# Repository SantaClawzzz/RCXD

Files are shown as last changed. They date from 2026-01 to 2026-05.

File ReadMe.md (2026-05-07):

## Introduction
Project repository for RC-XD project<br>
A remote controlled car Robotics Club project and Bachleor's thesis

The project is divided into 3 parts: Electronics, Mechanics, Programming<br>
Seperated by folders and ReadMe files on each of them.

### Design description

The project design description can be found [HERE](https://1drv.ms/w/c/367a3aeb31e11553/IQC-Zez4F6-2QIbnWiFFyMPwAU7Qmx2ZVu3_AnnbPPWjXhY?e=D11Og5)

### Timeline

The project timeline is [HERE](https://docs.google.com/document/d/1Baed8mpfqgpyJ5yqUqOmzXT9Kg_jJRIP0yAwD-ANLqw/edit?usp=sharing)

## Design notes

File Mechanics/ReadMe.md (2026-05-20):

# Info

All 3D print files for the car and controller adapter<br>
Small proto of the unfinished 433MHz controller

PCB files are also exported.

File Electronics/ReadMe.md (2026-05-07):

# Info
The PCBs both have 2 major revisions, (TMC and PreIDC have never been ordered).<br>
The newer ones will be documented with only changes mentioned about the previous revisions.

No document except the design description is present.

# TX

The transmitter PCB is essentialy the controller. Most of it is buttons and joystick routing with IDC connectors.<br>
Also includes 3.3V and 5V LDO regulators, where 5V is unused and routed to external header. 3.3V powers the MCU and logic pull-ups.<br>

## Components

The project has had 3 MCUs:
MCU:
  * ATMega328p-AU
  * ESP32-C6-WROOM-1U
  * STM32F103Cx

Buttons and joystick are routed to IDC headers which are easier to crimp by hand and allows for the mechanical design to be flexible. TX header is still the default 2.54mm header, which connection can be concerning as it doesn't have any locking mechanism.

Design is done with panelization in mind, so not every switch and joystick has to be ordered separately.
This only benefitial with larger quantities

* MCU - [STM32F103C6](/Electronics/Datasheets/stm32f103c6.pdf)
* Backup MCU [STM32F103C8](/Electronics/Datasheets/stm32f103c8.pdf)
* USB-UART chip [HT42B534-2](/Electronics/Datasheets/HT42B534-xv130.pdf)
* Battery - 7.4V [TBA]()
* Regulators:
  * [3V3 LDO](/Electronics/Datasheets/AMS1117.pdf)
  * [5V LDO](/Electronics/Datasheets/AMS1117-5.0.pdf)
* [USB-C](/Electronics/Datasheets/GCT_usb4085.pdf)
* [Button](/Electronics/Datasheets/TL2201.pdf)
* [Joystick](/Electronics/Datasheets/thb001p.pdf)
* [FS1000A](/Electronics/Datasheets/FS1000A_webpage.pdf) and the [module](/Electronics/Datasheets/433%20MHz%20RF%20Transmitter%20Module_0.pdf)

433MHz didn't work well, so TX was pushed aside and Flysky controller was brought in to use
* [FS-i6X](https://www.flysky-cn.com/fsi6x)

## Mechanical parameters:
  * 34.5mm x 80mm
    * Joystick (30mm x 24mm)
    * Button (16mm x 19mm)
    * MCU (34.5mm x 27.5mm)
  * M2 screws

## Power

LDOs are used since max current is ~100mA. 5V LDO is unused but connects with USB-C VBUS and cascades into 3.3V LDO. 5V is routed to an external header for possible future use.
Switching regulators take more space, cost more and require more thought into the design. Since there is no need, there is no need to use extra resources.

## Logic

For the logic and data processing the STM32F103Cx is used. C6 and C8 both have identical pinouts and only differ by the internal RAM size.<br>
STM32F103C6/8 design is based of the "Blue pill" and can be programmed in Arduino or STM32. STM is preferable as it gives lower level access and has faster data processing.<br>
A lot of pins are unused and this could be considered overkill for this design but it's the same MCU used for the RX, which saves time on complications and differences on the two boards.

# RX

The receiver PCB is mostly the motor driver with logic being received from the RX PCB. So power paths are most crucial part of the design. It's quite tight and might have some errors.<br>
Instead of LDOs, switching regulators are used since the current draw is much higher.

## Components
The project has had 2 MCU and 1 motor driver change:
MCU:
  * ATMega328p-AU
  * ESP32-C6-WROOM-1U
  * STM32F103Cx

The STM chip has good ADC readings, USB OTG, reliable, librarys for STM32CubeIDE and Arduino and available resources / designs like the STM32 "Blue Pill"<br>
The video (which was planned at first with ESP32) will be done externally, with seperate VTX/RTX modules

DRV:
  * TMC5160/A
  * BTM9011

BTM chip was chosen after it was determined the TMC chip is for stepper motors and controls them assuming they're on one axis (meaning if ones slows down, is fked)
So with the BTM chip we gain:
  * Internal MOSFETS, so smaller design
  * Cheaper chip: 1.5€ vs 7€ (not including the external components)
  * Less complicated (PCB design as well as programming/datasheet)
  * Does what we actually want
  * Also it has current sensing and should have under- and overvoltage protection with current/stall protection

* MCU - [STM32F103C6](/Electronics/Datasheets/stm32f103c6.pdf)
* Backup MCU - [STM32F103C8](/Electronics/Datasheets/stm32f103c8.pdf)
* USB-UART chip [HT42B534-2](/Electronics/Datasheets/HT42B534-xv130.pdf)
* Driver - [BTM9011](/Electronics/Datasheets/BTM901xep.pdf)
* Battery - 12V [TBA]()
* Motors - [Pololu 4842](https://www.pololu.com/product/4842)
* Regulators - [5V buck](/Electronics/Datasheets/REN_RAA211803.pdf) and [3V3 LDO](/Electronics/Datasheets/NCP115-D.pdf)
* USB-C - [THT variant](/Electronics/Datasheets/GCT_usb4085.pdf)

* Includes headers for:
  * 3x [TOF](https://www.pololu.com/product/3415) sensors (I2C)
  * 1x [OLED](https://www.adafruit.com/product/931?srsltid=AfmBOooS0SgYaJRqBKaiZJ_inS_Hm55apfdVYE57VtUnGSEqd8KzymMf) screen (I2C) - No RST or VIN
  * 1x [XY-MK-5V](https://radiolux.com.ua/files/pdf/RFmodule.pdf) (GPIO)
  * 1x [FS-A8s](https://www.flysky-cn.com/a8sspecifications)

## Power
* 3S 12V battery, since motors are 12V
* 5A stall current but under load should hover less than 1A
* USB-C for programming and VBUS through diode to 5V

Main issue right now is the power for the motors, since they take 1A probably by normal and 5A at stall. So the traces should withstand 5A, but they at max withstand 2A.<br>
This should be fine but might need a redesign with v2 or even before the first batch.<br>
Also an idea is active cooling, so if the PCB can't withstand it maybe with active cooling it can

## Mechanical parameters
  * 37x40mm
  * M2 screws

## Logic

For the logic the same STM32F103Cx MCU is used.<br>
It takes in data from the TX PCB and gives signals to the drivers, gets data through SPI from drivers and also current sense which it has to do on RX board since it has no way of sending info to the TX board.<br>
Some extra pins are drawn to unused GPIO headers.

# VX

Video part is completely seperate system, no PCB currently but schematic is made in Altium<br>
Mostly plug and play, TX06 camera only need power (4 in 1 system).<br>
Receiver needs 2 electrolytic capacitors (470uF), wiring and antenna. Video soldered straigth to display, needs to have proper RCA jack

## Components
* Car
  * [TX06](https://www.eachine.com/Eachine-TX06-700TVL-FOV-130-Degree-5_8Ghz-40CH-Smart-Audio-Mini-FPV-Camera-AIO-Transmitter-For-RC-Dr-p-1418.html)
  * 1S battery - Picture below
* Controller
  * Protoboard
  * 2x 470uF electrolytic capacitors
  * [U.FL antenna connector](https://www.digikey.com/en/products/detail/te-connectivity-amp-connectors/2337019-1/9974052)
  * [Antenna](https://www.digikey.com/en/products/detail/yic/ATIF2458G-3010/21804188)
  * Screen - Picture below
  * 2S or 3S battery

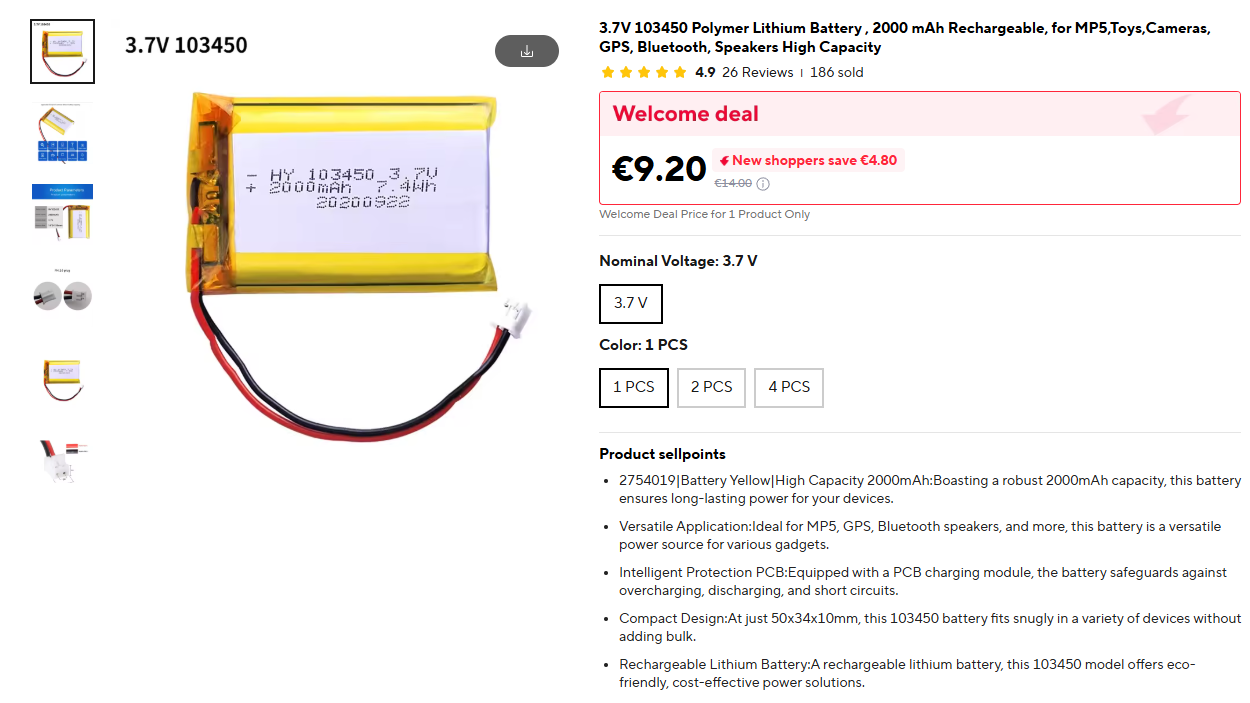
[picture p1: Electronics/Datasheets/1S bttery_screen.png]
battery

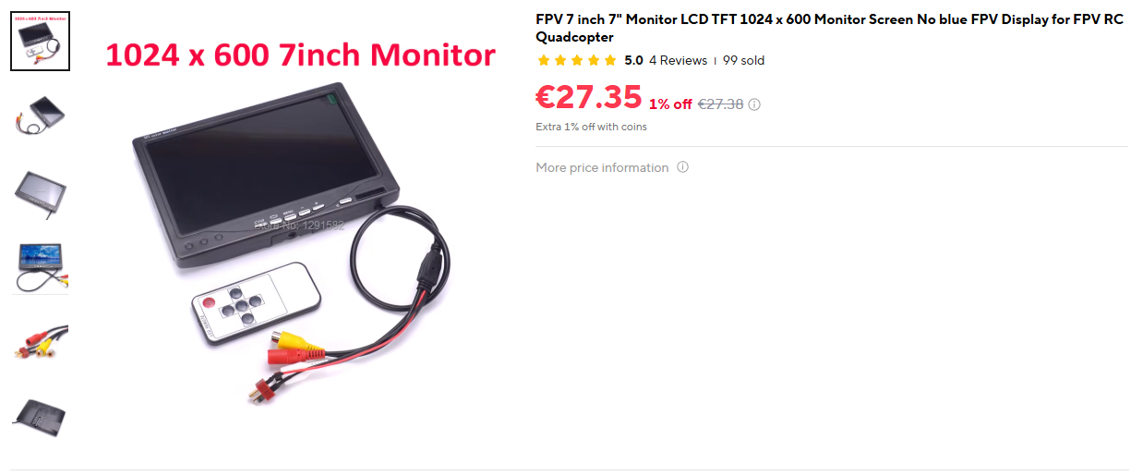
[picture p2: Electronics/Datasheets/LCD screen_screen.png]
screen


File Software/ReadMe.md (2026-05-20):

# Info

This folder contains all STM32 firmware projects for the RC-XD, written in STM32CubeIDE using HAL.<br>
All three projects target the STM32F103Cx (C6 or C8 — identical pinout, differ only in flash/RAM size).

## Projects

### TX_C6 — 433 MHz Transmitter (deprecated)

Custom transmitter firmware for the TX PCB.<br>
Reads joystick position via ADC, encodes a BTM9011 motor command, and transmits it over 433 MHz using the FS1000A module with a custom RF433 driver (RadioHead RH_ASK compatible, 2000 bps OOK).<br>
Abandoned because 433 MHz performance was too unreliable.

### RX_C8 — 433 MHz Receiver (deprecated)

Companion receiver firmware for the RX PCB, paired with TX_C6.<br>
Receives 433 MHz packets via the XY-MK-5V module and forwards decoded commands to two daisy-chained BTM9011 motor drivers over SPI.<br>
Abandoned alongside TX_C6 when 433 MHz was dropped.

### RX_C6 — iBUS Receiver (current)

Current working firmware for the RX PCB.<br>
Replaces the custom 433 MHz link with the Flysky FS-A8s 2.4 GHz receiver, reading channel data via the iBUS protocol over UART with DMA.<br>
Controls two daisy-chained BTM9011 motor drivers and a servo, with deadzone handling and clamped PWM steps.

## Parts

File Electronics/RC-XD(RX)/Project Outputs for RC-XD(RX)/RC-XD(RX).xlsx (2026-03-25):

Comment | Description | Designator | Footprint | LibRef | Quantity
4.7u | MLCC, 0603, 4.7u, 10%, 35V, X5R | C200, C201 | MLCC_0603_M | CMP-001-1257-1 | 2
100n | MLCC, 0603, 100n, 10%, 35V, X7R, MLCC, 0603, 100n, 10%, 50V, X7R | C202, C203, C400, C401, C402, C404, C409, C411, C500, C501, C502, C503, C504, C505 | MLCC_0603_M | CMP-001-0755-1, CMP-001-0815-1 | 14
15p | MLCC, 0603, 15p, 5%, 50V, C0G/NP0 | C204, C205 | MLCC_0603_M | CMP-001-0474-1 | 2
1u | MLCC, 0603, 1u, 10%, 50V, X5R | C300, C301, C408, C410 | MLCC_0603_M | CMP-001-0565-1 | 4
22u | MLCC, 0603, 22u, 10%, 16V, X5R | C303, C304 | MLCC_0603_M | CMP-001-1264-1 | 2
4.7u | MLCC, 1206, 4.7u, 10%, 35V, X5R | C305 | MLCC_1206_M | CMP-001-1124-2 | 1
4.7u | MLCC, 0805, 4.7u, 20%, 50V, X5R | C403 | MLCC_0805_M | CMP-001-1830-1 | 1
15p | MLCC, 0402, 15p, 10%, 25V, C0G/NP0 | C405, C406 | MLCC_0402_M | CMP-001-1853-1 | 2
1n | MLCC, 0603, 1n, 10%, 50V, X5R | C407 | MLCC_0603_M | CMP-001-0547-1 | 1
MBR1020VL_R1_00001 | Rectifier Diode, Schottky, 1 Phase, 1 Element, 1A, 20V V(RRM), Silicon | D300, D400 | FP-MBR1020VL_R1_00001-MFG | CMP-ROOT-01310-1 | 2
VSSAF3M10HM3/H | Rectifier Diode, Schottky, 1 Phase, 1 Element, 2.3A, 100V V(RRM), Silicon, DO-221AC | D302 | VSSAF3M10HM3_H-Footprint-1 | CMP-ROOT-01308-1 | 1
Red | Generic red 0603 LED | D303, D304, D305, D306 | 0603 RED LED | CMP-ROOT-00025-2 | 4
1N5817G | Rectifier Diode, Schottky, 1 Phase, 1 Element, 1A, 20V V(RRM), Silicon, DO-204AL | D401 | SOD-323 based on 1N5817WS | CMP-ROOT-01323-1 | 1
XT30U-F | Power Connector | J300 | XT30U-F | CMP-ROOT-01262-3 | 1
USB4085-GF-A | USB Connector, 16 Contact(s), Female, Right Angle, Solder Terminal, Locking, Receptacle | J400 | FP-USB4085-GF-A-MFG | CMP-001-1800-1 | 1
7-215079-6 | Conn FFC Connector F 6 POS 1.27mm Solder ST Thru-Hole Automotive Box/Carton | J500, J501, J502 | 7-215079-6-Footprint-1 | CMP-ROOT-01311-2 | 3
0878310641 | Conn Shrouded Header (2 Sides) HDR 6 POS 2mm Solder ST Top Entry Thru-Hole Milli-Grid Tube | J503, J504 | 0878310641 | CMP-ROOT-01318-3 | 2
74404043220A | General Purpose Inductor, 22uH, 20%, 1 Element, Nickel-zinc Ferrite-Core, SMD, 1616 | L301 | WE-LQS_4025 | CMP-ROOT-01309-1 | 1
PH1-04-UA | 4 POS 2.54mm Vertical THT Header | P500 | 4Pos Pin Header Vertical | CMP-002-000004-1 | 1
M20-9990345 | Connector Header Through Hole 3 position 0.100" (2.54mm) | P503 | 3Pos Pin Header | CMP-ROOT-00217-1 | 1
61300511121 | Conn Unshrouded Header HDR 5 POS 2.54mm Solder ST Top Entry Thru-Hole Bag | P504, P505 | 61300511121 | CMP-ROOT-01020-1 | 2
2k | Resistor, 0603, 2k, 1%, 1/10W | R200 | Resistor_0603_M | CMP-001-0084-2 | 1
22R | Resistor, 0603, 22R, 1%, 1/10W | R201, R202, R203, R204, R205, R206, R207, R405, R406, R500 | Resistor_0603_M | CMP-001-0038-3 | 10
680R | Resistor, 0603, 680R, 1%, 1/10W | R300 | Resistor_0603_M | CMP-001-0074-3 | 1
200R | Resistor, 0603, 200R, 1%, 1/10W | R301, R303 | Resistor_0603_M | CMP-001-0060-2 | 2
100R | Resistor, 0603, 100R, ≤5%, ≥1/16W, Resistor, 0603, 100R, 1%, 1/10W | R302, R401, R504 | Resistor_0603_M | CMP-0001-00262-1, CMP-001-0054-5 | 3
10k | Resistor, 0603, 10k, 1%, 1/10W, Resistor, 0603, 10k, ≤5%, ≥1/16W | R400, R501, R502, R503 | Resistor_0603_M | CMP-001-0101-2, CMP-0001-00257-1 | 4
5.1k | Resistor, 0603, 5.1k, 1%, 1/10W | R402, R403 | Resistor_0603_M | CMP-001-0094-2 | 2
1.5k | Resistor, 0603, 1.5k, 1%, 1/10W | R404 | Resistor_0603_M | CMP-001-0081-2 | 1
1M | Resistor, 1206, 1M, 1%, 1/4W | R407 | Resistor_1206_M | CMP-0001-00051-1 | 1
4.7k | Resistor, 0603, 4.7k, 1%, 1/10W | R409, R410 | Resistor_0603_M | CMP-001-0093-2 | 2
USLPT2819DT4TR | Keypad Switch, SPST, 0.05A, 1.96N, Solder Terminal, Panel Mount | S400 | USLPT2819DT4TR-Footprint-1 | CMP-ROOT-01290-1 | 1
BTM9011EPXUMA1 | DC Mtr Drive, Brush, 150DEGC, TSSOPEP-14 Rohs Compliant: Yes | U200, U201 | BTM9011EPXUMA1 | CMP-00022-3 | 2
NCP115ASN330T2G | LDO Regulator, 300 mA, Low Iq, High PSRR, High Accuracy 3.3V, TSOP5, Active Discharge, Normal Vout Slew-Rate | U300 | TSOP-5 | CMP-00026-1 | 1
RAA2118054GP3#JA0 | Switching Regulator, Current-mode, 0.3A, 230kHz Switching Freq-Max, PDSO5 | U301 | P5_064B_MFG | CMP-00019-3 | 1
STM32F103C8T6 | MCU 32-bit STM32F1 ARM Cortex M3 RISC 64KB Flash 2.5V/3.3V 48-Pin LQFP Tray | U400 | STM-LQFP48_M | CMP-00012-3 | 1
HT42B534-2 | USB to UART 3Mbps USB 2.0 SOP-8 Interface Controllers RoHS | U401 | SOP-8 150mil | CMP-00027-2 | 1
XY-MK-5V RF | 433MHz reciever module, 5V tolerant | U500 | 2.54mm 4 POS XY-MK-5V RF | CMP-00015-1 | 1
ABM11-16.000MHZ-12-N1G-T | Crystal 16MHz ±10ppm (Tol) ±15ppm (Stability) 12pF FUND 150Ohm 4-Pin Ultra Mini-CSMD T/R | Xtal400 | FP-ABM11-MFG | CMP-ROOT-01254-3 | 1

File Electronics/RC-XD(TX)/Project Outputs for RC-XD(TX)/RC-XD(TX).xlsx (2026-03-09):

Comment | Description | Designator | Footprint | LibRef | Quantity
4.7u | MLCC, 0805, 4.7u, 20%, 50V, X5R | C100 | MLCC_0805_M | CMP-001-1830-1 | 1
100n | MLCC, 0603, 100n, 10%, 50V, X7R | C101, C102, C103, C105, C111, C112, C113, C114, C115, C116, C119, C120, C121 | MLCC_0603_M | CMP-001-0815-1 | 13
1u | MLCC, 0603, 1u, 10%, 50V, X5R | C104 | MLCC_0603_M | CMP-001-0565-1 | 1
1n | MLCC, 0603, 1n, 10%, 50V, X7R | C106 | MLCC_0603_M | CMP-001-0786-1 | 1
10u | MLCC, 0805, 10u, 10%, 50V, X5R | C107, C109 | MLCC_0805_M | CMP-001-0829-2 | 2
TCJB226M025R0150 | Cap Tant Solid 22uF 25V B CASE 20% (3.5 X 2.8 X 1.9mm) SMD 3528-21 0.15 Ohm 105°C T/R | C108, C110 | 1210_Tantalum | CMP-0001-00036-4 | 2
15p | MLCC, 0402, 15p, 10%, 25V, C0G/NP0 | C117, C118 | MLCC_0402_M | CMP-001-1853-1 | 2
MBR1020VL_R1_00001 | Rectifier Diode, Schottky, 1 Phase, 1 Element, 1A, 20V V(RRM), Silicon | D100 | FP-MBR1020VL_R1_00001-MFG | CMP-ROOT-01310-1 | 1
SP0503BAHT | SP050xBA Series 8.5 V 30 pF Triple Uni-Directional TVS Avalanche Diode-SOT143-4 | D101 | LFUS-SOT143-4_V | CMP-ROOT-01259-1 | 1
Red | Generic red 0603 LED | D102, D103, D104 | 0603 RED LED | CMP-ROOT-00025-2 | 3
USB4085-GF-A | USB Connector, 16 Contact(s), Female, Right Angle, Solder Terminal, Locking, Receptacle | J100 | FP-USB4085-GF-A-MFG | CMP-001-1800-1 | 1
7-215079-6 | Conn FFC Connector F 6 POS 1.27mm Solder ST Thru-Hole Automotive Box/Carton | J101, J102 | 7-215079-6-Footprint-1 | CMP-ROOT-01311-2 | 2
7-215079-4 | Conn FFC Connector F 4 POS 1.27mm Solder ST Thru-Hole Box/Carton | J103, J104, J105 | 7-215079-4 | CMP-ROOT-01314-1 | 3
8 Pos Vertical Pin Header | Connector Header Through Hole 8 position 0.100" (2.54mm) | P100 | 8 POS Vertical Pin Header | CMP-ROOT-00235-2 | 1
S2B-PH-K-S(LF)(SN) | Conn Shrouded Header (4 Sides) HDR 2 POS 2mm Solder RA Thru-Hole Box | P101 | B5B-PH-K-S(LF)(SN) | CMP-ROOT-00728-2 | 1
PH1-02-UA | Conn Unshrouded Header HDR 2 POS 2.54mm Solder ST Top Entry Thru-Hole Bag | P102 | 2Pos Pin Header Vertical | CMP-002-000007-1 | 1
61300511121 | Conn Unshrouded Header HDR 5 POS 2.54mm Solder ST Top Entry Thru-Hole Bag | P103 | 61300511121 | CMP-ROOT-01020-1 | 1
5.1k | Resistor, 0603, 5.1k, 1%, 1/10W | R100, R101 | Resistor_0603_M | CMP-001-0094-2 | 2
22R | Resistor, 0603, 22R, 1%, 1/10W | R102, R103, R121 | Resistor_0603_M | CMP-001-0038-3 | 3
1M | Resistor, 1206, 1M, 1%, 1/4W | R104 | Resistor_1206_M | CMP-0001-00051-1 | 1
200R | Resistor, 0603, 200R, 1%, 1/10W | R105, R106, R107 | Resistor_0603_M | CMP-001-0060-2 | 3
10k | Resistor, 0603, 10k, 1%, 1/10W, Resistor, 0603, 10k, ≤5%, ≥1/16W | R108, R110, R111, R112, R116, R118, R120 | Resistor_0603_M | CMP-001-0101-2, CMP-0001-00257-1 | 7
100R | Resistor, 0603, 100R, 1%, 1/10W | R109, R113, R114, R115, R117, R119 | Resistor_0603_M | CMP-001-0054-5 | 6
4.7k | Resistor, 0603, 4.7k, 1%, 1/10W | R122, R123 | Resistor_0603_M | CMP-001-0093-2 | 2
THB001P | Multi-Directional Thumbstick, 2 Axis, Center Momentary Switch, 12VDC, THB Series | S100 | THB001P | CMPL-001-A00000-7 | 1
USLPT2819DT4TR | Keypad Switch, SPST, 0.05A, 1.96N, Solder Terminal, Panel Mount | S101 | USLPT2819DT4TR-Footprint-1 | CMP-ROOT-01290-1 | 1
TL2201EEXB | Pushbutton Switch, DPDT, ON-ON, 100 mA, 30V DC, PC Pin, TL2201 Series | SW100, SW102 | TL2201EEXB-Footprint-1 | CMP-ROOT-01258-1 | 2
JS202011CQN | Slide Switch, 1 Positions, Dpdt, Latched, 0.3A, 6Vdc, 6 Pcb Hole Cnt, Solder Terminal, Through | SW101 | FP-JS202011CQN-MFG | CMP-ROOT-01260-4 | 1
STM32F103C6T6A | MCU 32-bit STM32F ARM Cortex M3 RISC 32KB Flash 2.5V/3.3V 48-Pin LQFP Tray | U100 | STM-LQFP48_M | CMP-00012-1 | 1
FS1000A | FS1000A 433MHZ RF transmitter & XY-MK-5V Receiver Module | U101 | 2.54mm 3-pin horizontal | CMP-ROOT-01261-3 | 1
AMS1117-5.0 | LDO Regulator Pos 5V 1A 4-Pin(3+Tab) SOT-223 / 1A LOW DROPOUT VOLTAGE REGULATOR | U102 | SOT230P700X180-4N | CMP-00014-1 | 1
AMS1117-3.3 | Gull Wing EAR99 Fixed Positive Single Output Ldo Regulator Dual Voltage Regulator Linear 125C 1.2W 1A 1.8MM | U103 | SOT-223 based on ZVP2110GTA | CMP-00009-1 | 1
ABM11-16.000MHZ-12-N1G-T | Crystal 16MHz ±10ppm (Tol) ±15ppm (Stability) 12pF FUND 150Ohm 4-Pin Ultra Mini-CSMD T/R | Xtal100 | FP-ABM11-MFG | CMP-ROOT-01254-3 | 1

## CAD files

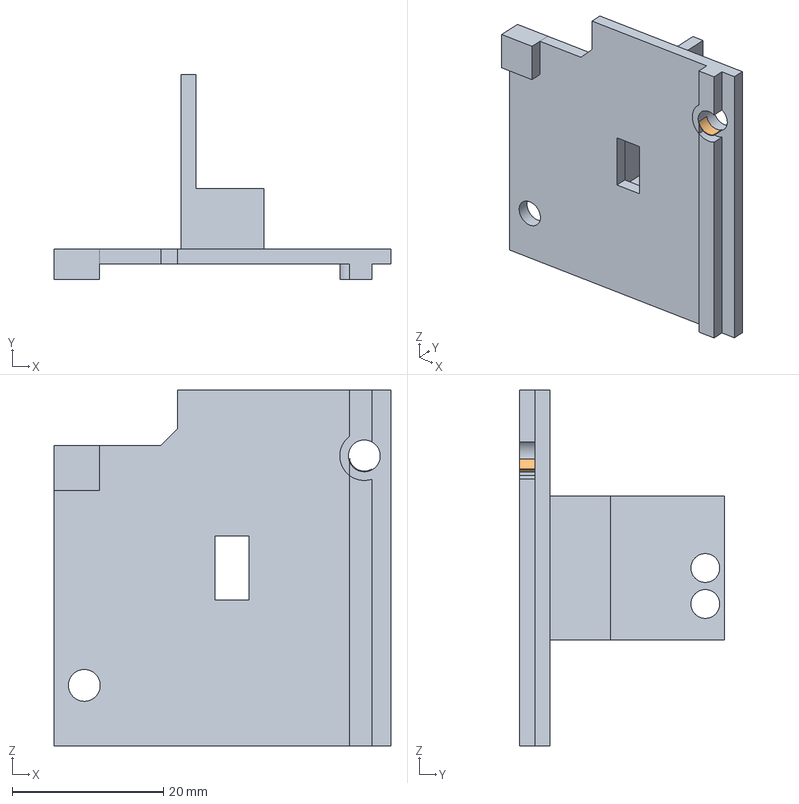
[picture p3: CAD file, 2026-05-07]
Mechanics/Car/Battery and RX plate/Vastuvõtja kinnitus.step
44.5 x 27.0 x 47.0 mm

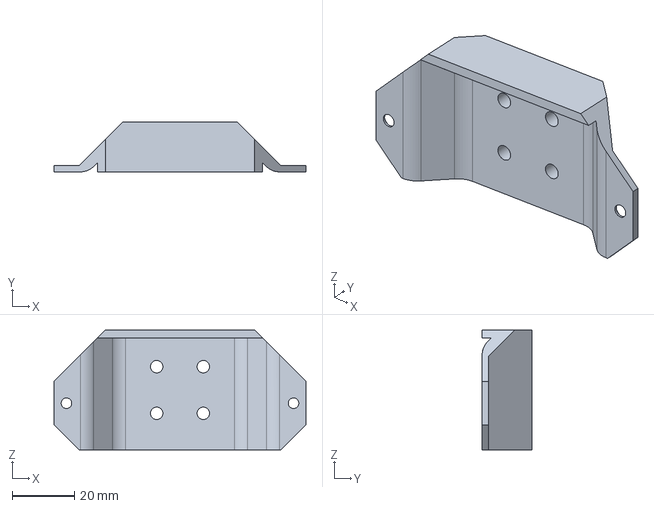
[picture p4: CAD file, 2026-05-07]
Mechanics/Car/Camera and Wheel Cover/Rataste kate.step
81.0 x 16.0 x 38.5 mm

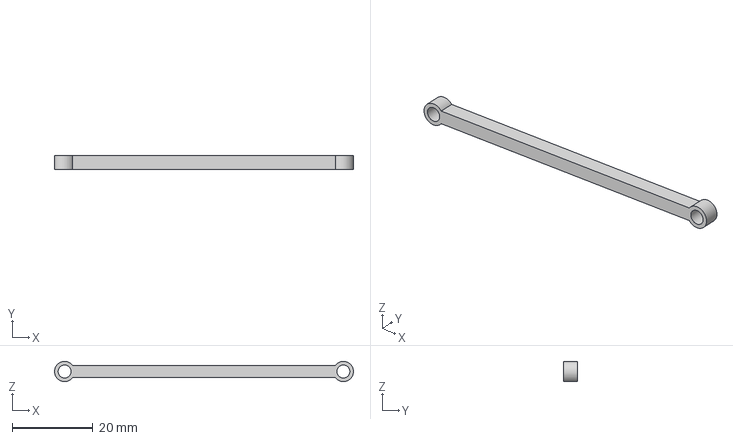
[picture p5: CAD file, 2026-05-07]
Mechanics/Car/Front Wheels and Servo/Servo stabilisaator.step
73.8 x 3.50 x 4.99 mm

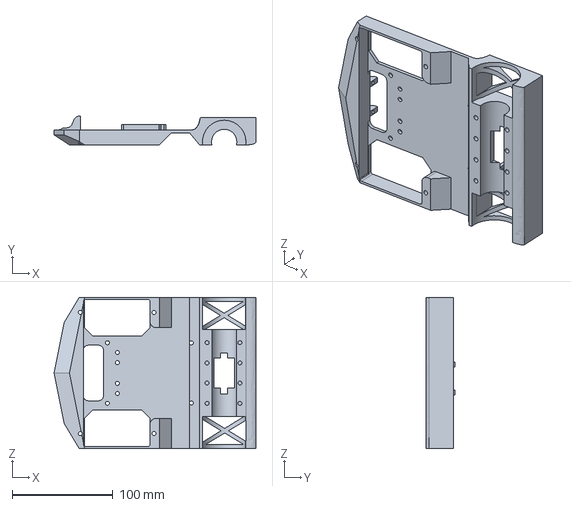
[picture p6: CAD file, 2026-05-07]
Mechanics/Car/Kere.step
200.0 x 28.6 x 150.0 mm

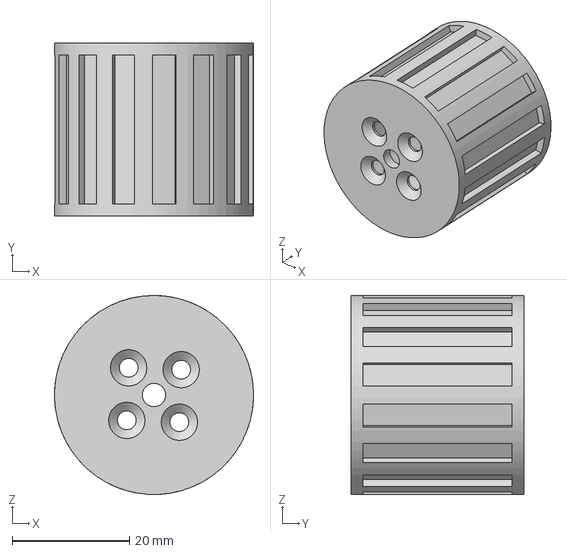
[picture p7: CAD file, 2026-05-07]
Mechanics/Car/Rear Wheels/Tagaratas.step
34.0 x 29.5 x 34.0 mm

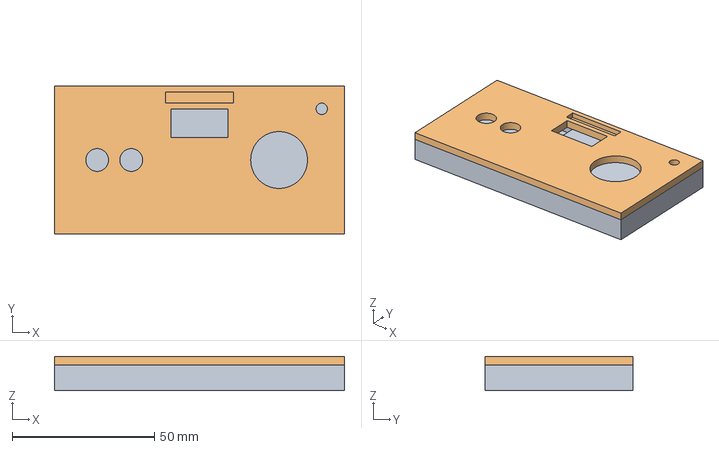
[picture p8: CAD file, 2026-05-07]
Mechanics/Controller and adapter/Proto 433MHz Controller.step
102.0 x 52.0 x 12.0 mm

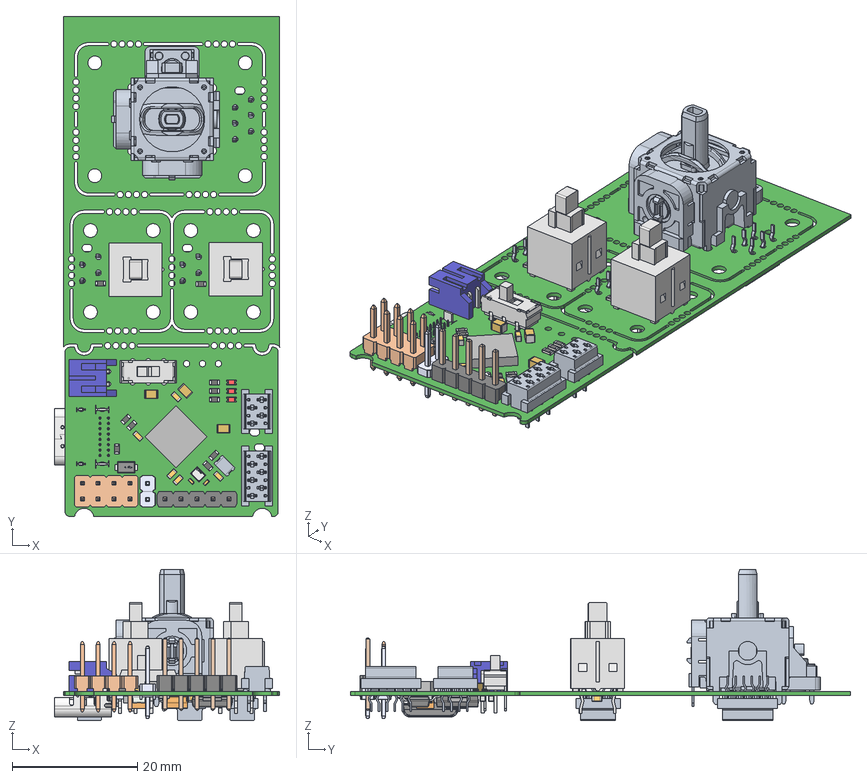
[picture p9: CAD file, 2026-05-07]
Mechanics/PCBs/TX.step
35.9 x 79.8 x 24.1 mm
CAPC1608X92N EIA 0603 x 13
6130xx11121_PIN x 5
RESC1608 EIA 0603 x 20
PH1-02-UA
LED Red SMD 0603 Würth 150060SS55040 x 3
Package
Pins
Mark
Logo
TLJB157M010R0500-HICV_TLJ_B-KYOCERA_AVX-TAN x 2
961208-6404-XX
141_TL2201xxXB x 2
c-2337225-2-b-3d
Crys_Abracon_ABM11-44_000MHZ-B7G-T_eec x 6
Lead x 3
Tab
Extruded x 2
Switch_C&K_JS202011CQN_eec
THB001P_PART1
THB001P_PART2
THB001P_PART3
THB001P_PART4
THB001P_PART5
THB001P_PART6
THB001P_PART7
THB001P_PART8
CircuitWorks-RESISTOR 1206
S2B-PH-K-S
USB4085-GF-A_PART1
GCT
CAPC1005X55N EIA 0402 x 4

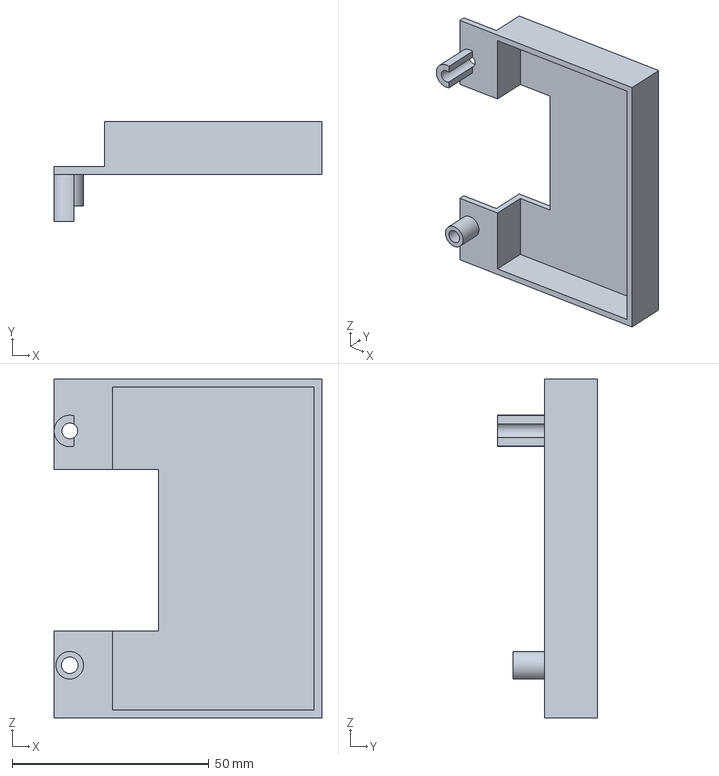
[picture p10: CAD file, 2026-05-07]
Mechanics/Car/Battery and RX plate/Aku korpus.step
68.0 x 25.5 x 86.1 mm

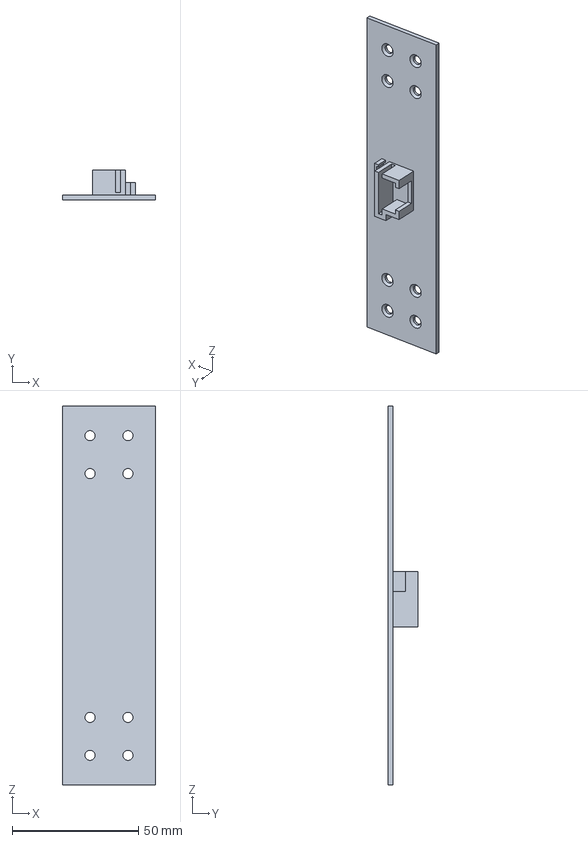
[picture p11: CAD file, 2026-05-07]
Mechanics/Car/Camera and Wheel Cover/Kaamera alus.step
37.0 x 12.0 x 150.0 mm

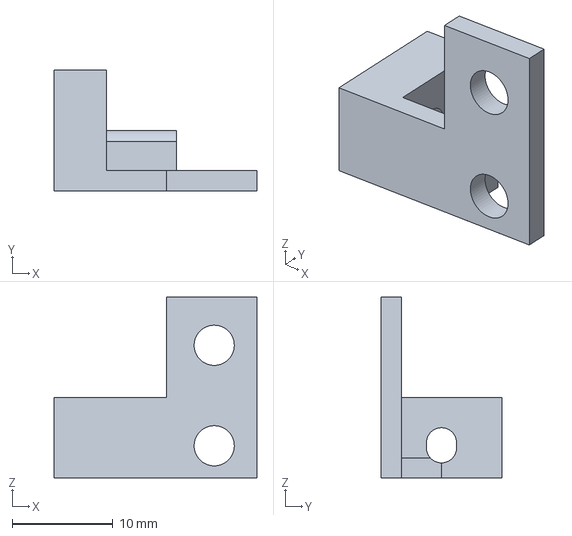
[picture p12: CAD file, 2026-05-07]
Mechanics/Car/Front Wheels and Servo/Servo parem kinnitus.step
20.2 x 12.0 x 18.0 mm

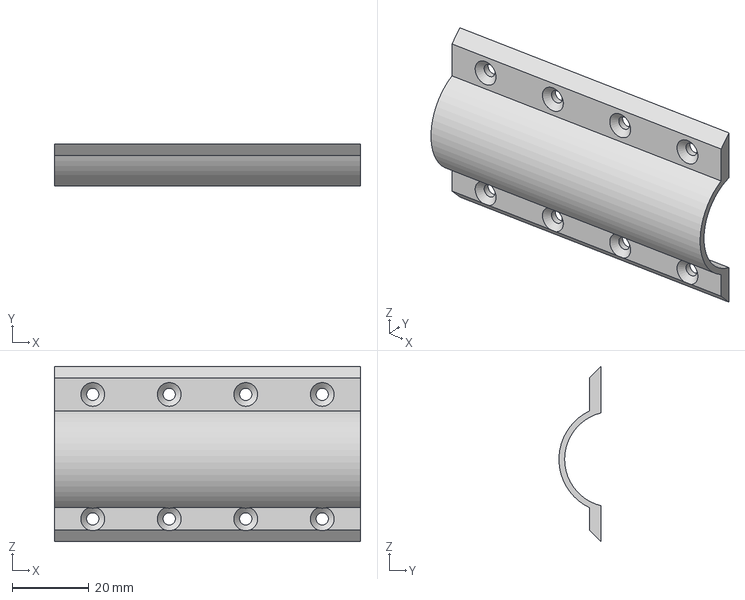
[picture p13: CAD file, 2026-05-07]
Mechanics/Car/Rear Wheels/Tagaratta hoidik.step
80.0 x 11.0 x 45.8 mm

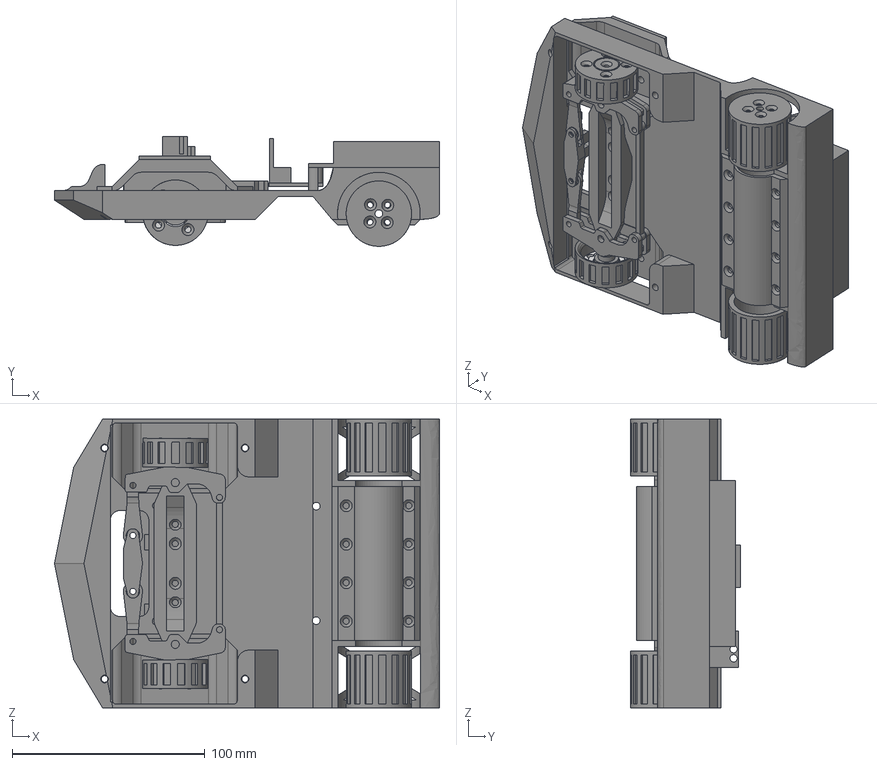
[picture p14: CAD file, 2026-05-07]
Mechanics/Car/Tervik Mudelauto.step
200.0 x 57.0 x 150.0 mm

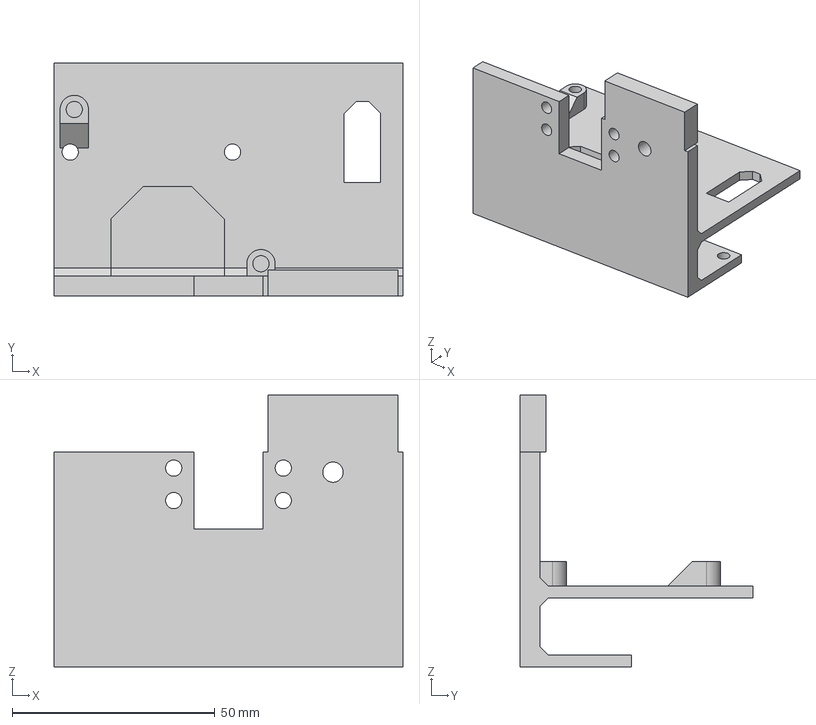
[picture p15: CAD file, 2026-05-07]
Mechanics/Controller and adapter/Flysky Screen Adapter.step
86.0 x 57.5 x 67.0 mm

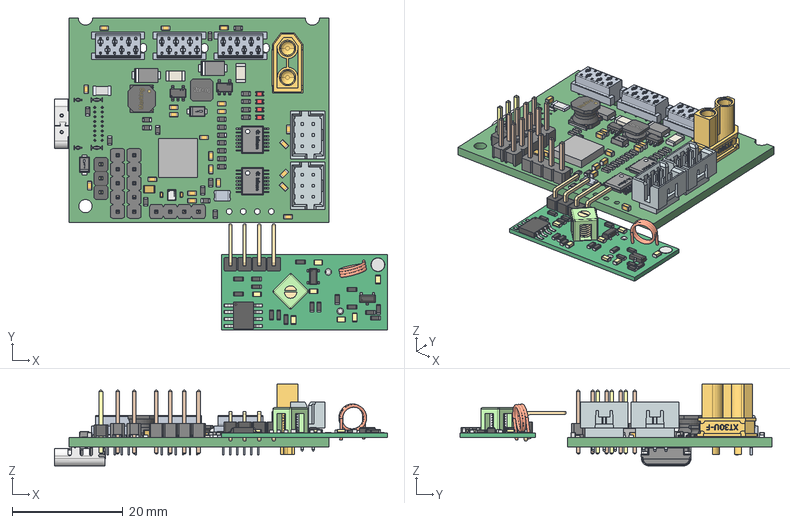
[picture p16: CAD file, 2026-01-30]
Mechanics/PCBs/RX.step
60.2 x 56.4 x 14.8 mm
RESC1608 EIA 0603 x 23
6130xx11121_PIN x 14
User Library-Header_Male_3Pin_PinArray
User Library-Header_Male_3Pin_BodyArray
CAPC1608X92N EIA 0603 x 21
XT30U
housing
contact x 2
spule
Glue x 2
SOT95P280X110-5_P5.064B_N x 2
PG-TSDSO-14-8 x 2
CircuitWorks-RESISTOR 1206
PinKIdent x 2
PinK x 2
PinA x 2
Crys_Abracon_ABM11-44_000MHZ-B7G-T_eec x 6
Extruded x 7
c-2337225-2-b-3d
Core
Contact x 2
USB4085-GF-A_PART1
GCT
Package x 2
Pins x 2
Mark x 2
Logo x 2
LED Red SMD 0603 Würth 150060SS55040 x 4
CAPC1005X55N EIA 0402 x 4

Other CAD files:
Mechanics/Car/Front Wheels and Servo/Servo vasak kinnitus.step
Mechanics/Car/Front Wheels and Servo/Servo liigend.step
Mechanics/Car/Front Wheels and Servo/Esiratta rumm.step
Mechanics/Car/Front Wheels and Servo/Esiratta kork.step
Mechanics/Car/Battery and RX plate/Aku korpus.f3d
Mechanics/Car/Battery and RX plate/Vastuvõtja kinnitus.f3d
Mechanics/Car/Camera and Wheel Cover/Kaamera alus.f3d
Mechanics/Car/Camera and Wheel Cover/Rataste kate.f3d
Mechanics/Car/Front Wheels and Servo/Esiratas.f3d
Mechanics/Car/Front Wheels and Servo/Esiratas.step
Mechanics/Car/Front Wheels and Servo/Esirataste hoidik.f3d
Mechanics/Car/Front Wheels and Servo/Esirataste hoidik.step
Mechanics/Car/Front Wheels and Servo/Esiratta kork.f3d
Mechanics/Car/Front Wheels and Servo/Esiratta rumm.f3d
Mechanics/Car/Front Wheels and Servo/Rattarummi kinnitus.f3d
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

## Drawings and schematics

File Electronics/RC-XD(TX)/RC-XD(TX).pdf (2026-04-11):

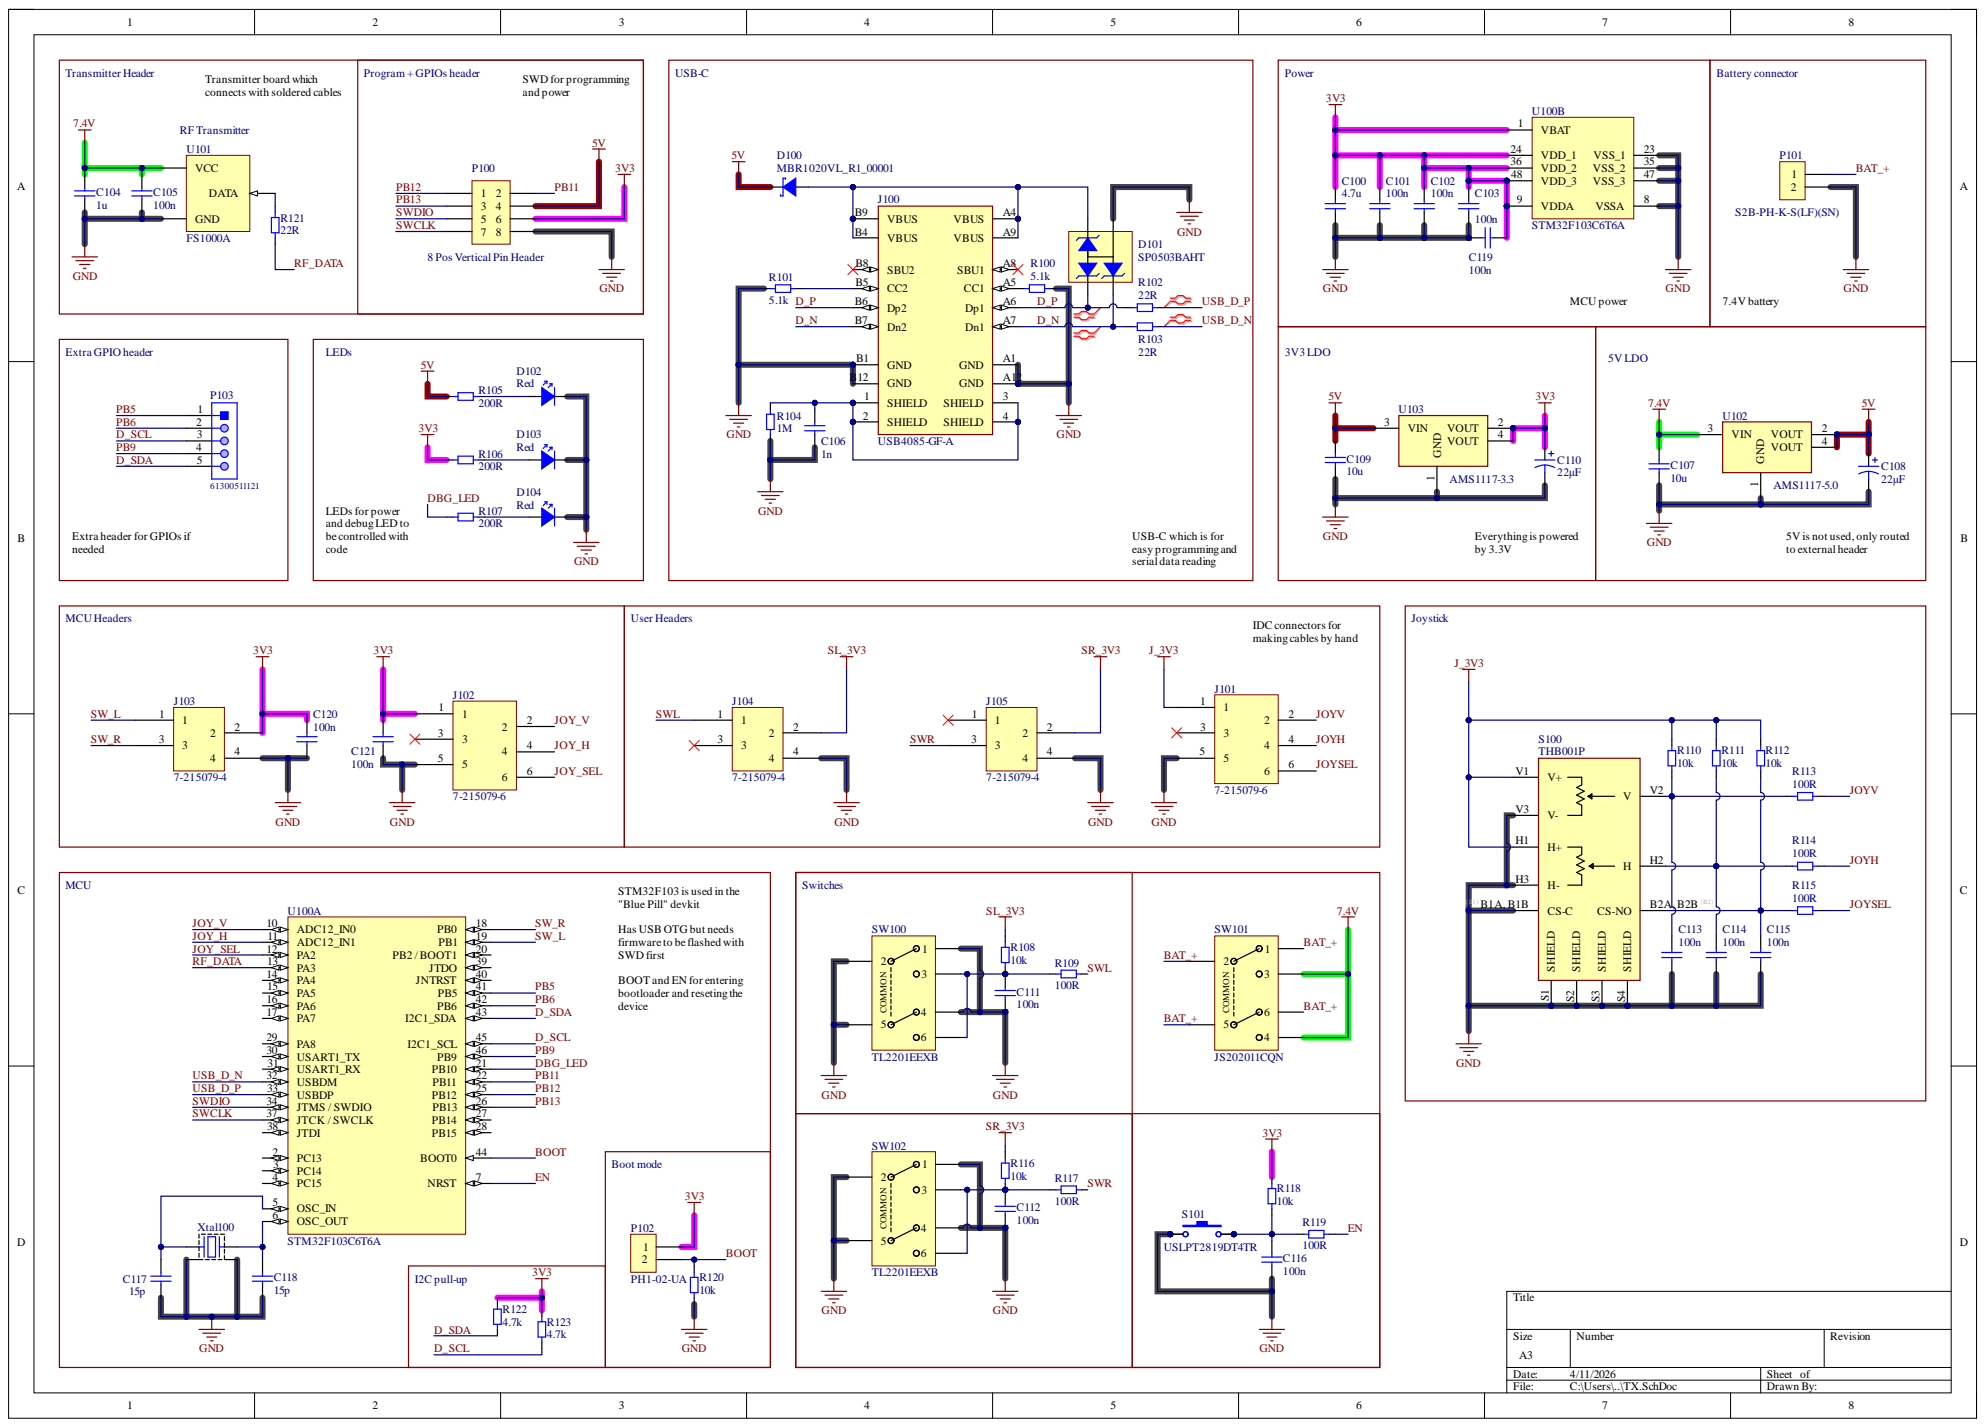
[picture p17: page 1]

Transmitter board which
connects with soldered cables

8 Pos Vertical Pin Header

Extra header for GPIOsif
needed

USB-C which is for
easy programming and
serial data reading

5V is not used, only routed
to external header

IDC connectorsfor
making cables by hand

STM32F103 is used in the
"Blue Pill" devkit

Has USB OTG but needs
firmware to be flashed with
SWD first

BOOT and EN for entering
bootloader and reseting the
device

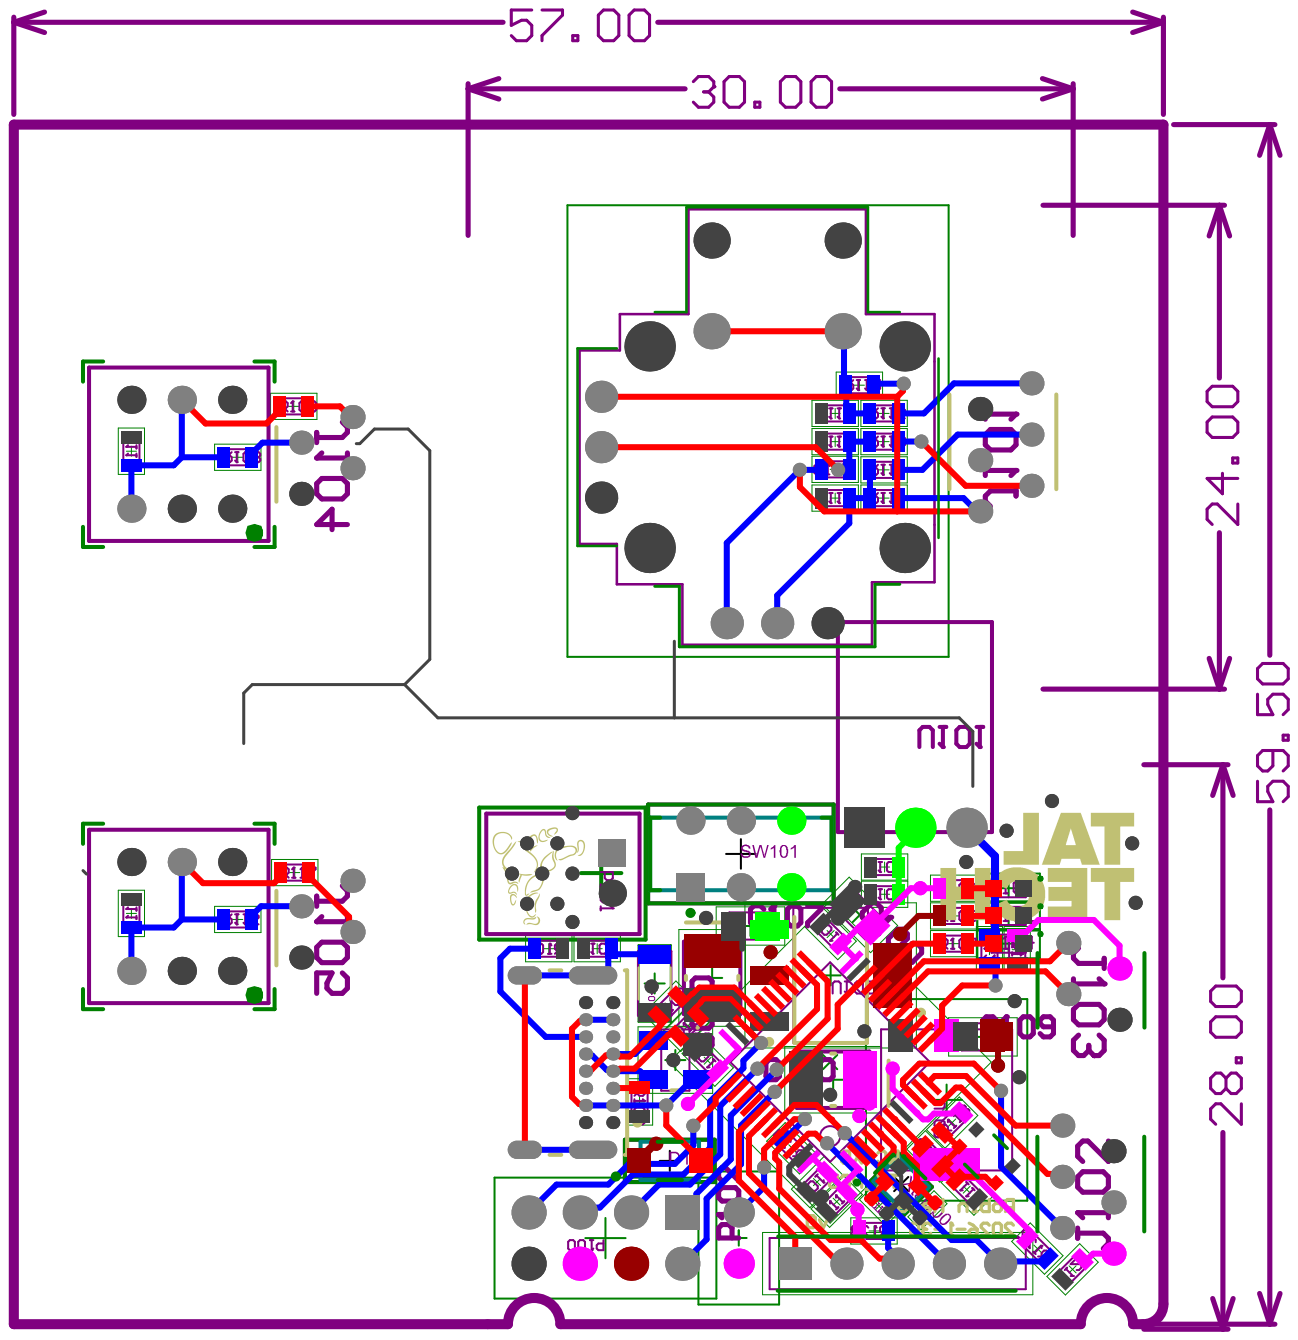
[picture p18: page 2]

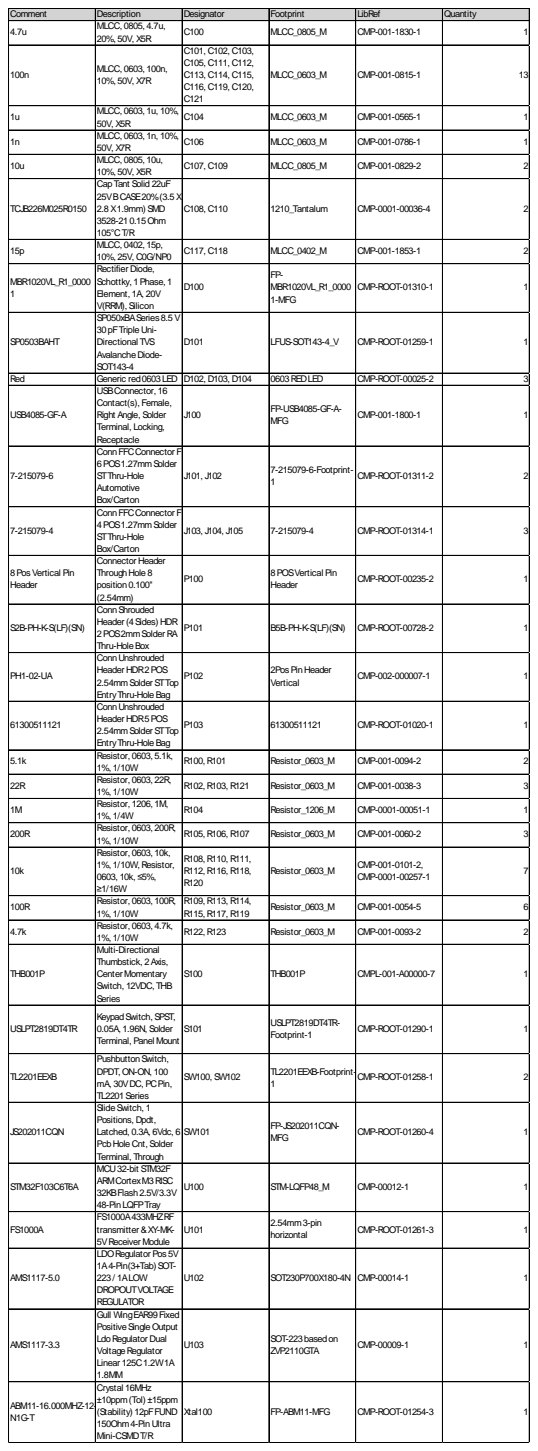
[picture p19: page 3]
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

1u | MLCC, 0603, 1u, 10%, 50V, X5R | C104 | MLCC_0603_M | CMP-001-0565-1 | 1

1n | MLCC, 0603, 1n, 10%, 50V, X7R | C106 | MLCC_0603_M | CMP-001-0786-1 | 1

10u | MLCC, 0805, 10u, 10%, 50V, X5R | C107, C109 | MLCC_0805_M | CMP-001-0829-2 | 2

TCJB226M025R0150 | CapTant Solid 22uF 25VBCASE20%(3.5X 2.8X1.9mm) SMD 3528-210.15Ohm 105°CT/R | C108, C110 | 1210_Tantalum | CMP-0001-00036-4 | 2

15p | MLCC, 0402, 15p, 10%, 25V, C0G/NP0 | C117, C118 | MLCC_0402_M | CMP-001-1853-1 | 2

MBR1020VL_R1_0000 1 | Rectifier Diode, Schottky, 1Phase, 1 Element, 1A, 20V V(RRM), Silicon | D100 | FP-MBR1020VL_R1_0000 1-MFG | CMP-ROOT-01310-1 | 1

SP0503BAHT | SP050xBASeries8.5V 30pFTriple Uni-Directional TVS AvalancheDiode-SOT143-4 | D101 | LFUS-SOT143-4_V | CMP-ROOT-01259-1 | 1

Red | Generic red0603LED | D102, D103, D104 | 0603REDLED | CMP-ROOT-00025-2 | 3
USB4085-GF-A | USBConnector, 16 Contact(s), Female, Right Angle, Solder Terminal, Locking, Receptacle | J100 | FP-USB4085-GF-A-MFG | CMP-001-1800-1 | 1

7-215079-6 | ConnFFCConnector F 6POS1.27mmSolder STThru-Hole Automotive Box/Carton | J101, J102 | 7-215079-6-Footprint-1 | CMP-ROOT-01311-2 | 2

7-215079-4 | ConnFFCConnector F 4POS1.27mmSolder STThru-Hole Box/Carton | J103, J104, J105 | 7-215079-4 | CMP-ROOT-01314-1 | 3

8PosVertical Pin Header | Connector Header ThroughHole 8 position0.100" (2.54mm) | P100 | 8POSVertical Pin Header | CMP-ROOT-00235-2 | 1

S2B-PH-K-S(LF)(SN) | ConnShrouded Header (4Sides) HDR 2POS2mmSolder RA Thru-HoleBox | P101 | B5B-PH-K-S(LF)(SN) | CMP-ROOT-00728-2 | 1

PH1-02-UA | ConnUnshrouded Header HDR2POS 2.54mmSolder STTop EntryThru-HoleBag | P102 | 2PosPinHeader Vertical | CMP-002-000007-1 | 1

61300511121 | ConnUnshrouded Header HDR5POS 2.54mmSolder STTop EntryThru-HoleBag | P103 | 61300511121 | CMP-ROOT-01020-1 | 1

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

22R | Resistor, 0603, 22R, 1%, 1/10W | R102, R103, R121 | Resistor_0603_M | CMP-001-0038-3 | 3

1M | Resistor, 1206, 1M, 1%, 1/4W | R104 | Resistor_1206_M | CMP-0001-00051-1 | 1

200R | Resistor, 0603, 200R, 1%, 1/10W | R105, R106, R107 | Resistor_0603_M | CMP-001-0060-2 | 3

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

THB001P | Multi-Directional Thumbstick, 2Axis, Center Momentary Switch, 12VDC, THB Series | S100 | THB001P | CMPL-001-A00000-7 | 1

USLPT2819DT4TR | KeypadSwitch, SPST, 0.05A, 1.96N, Solder Terminal, Panel Mount | S101 | USLPT2819DT4TR-Footprint-1 | CMP-ROOT-01290-1 | 1

TL2201EEXB | PushbuttonSwitch, DPDT, ON-ON, 100 mA, 30VDC, PCPin, TL2201Series | SW100, SW102 | TL2201EEXB-Footprint-1 | CMP-ROOT-01258-1 | 2

JS202011CQN | SlideSwitch, 1 Positions, Dpdt, Latched, 0.3A, 6Vdc, 6 Pcb Hole Cnt, Solder Terminal, Through | SW101 | FP-JS202011CQN-MFG | CMP-ROOT-01260-4 | 1

STM32F103C6T6A | MCU32-bit STM32F ARMCortexM3RISC 32KBFlash2.5V/3.3V 48-Pin LQFPTray | U100 | STM-LQFP48_M | CMP-00012-1 | 1

FS1000A | FS1000A433MHZRF transmitter &XY-MK-5VReceiver Module | U101 | 2.54mm3-pin horizontal | CMP-ROOT-01261-3 | 1

AMS1117-5.0 | LDORegulator Pos5V 1A4-Pin(3+Tab) SOT-223/ 1ALOW DROPOUTVOLTAGE REGULATOR | U102 | SOT230P700X180-4N | CMP-00014-1 | 1

AMS1117-3.3 | Gull WingEAR99Fixed PositiveSingle Output LdoRegulator Dual VoltageRegulator Linear 125C1.2W1A 1.8MM | U103 | SOT-223basedon ZVP2110GTA | CMP-00009-1 | 1

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

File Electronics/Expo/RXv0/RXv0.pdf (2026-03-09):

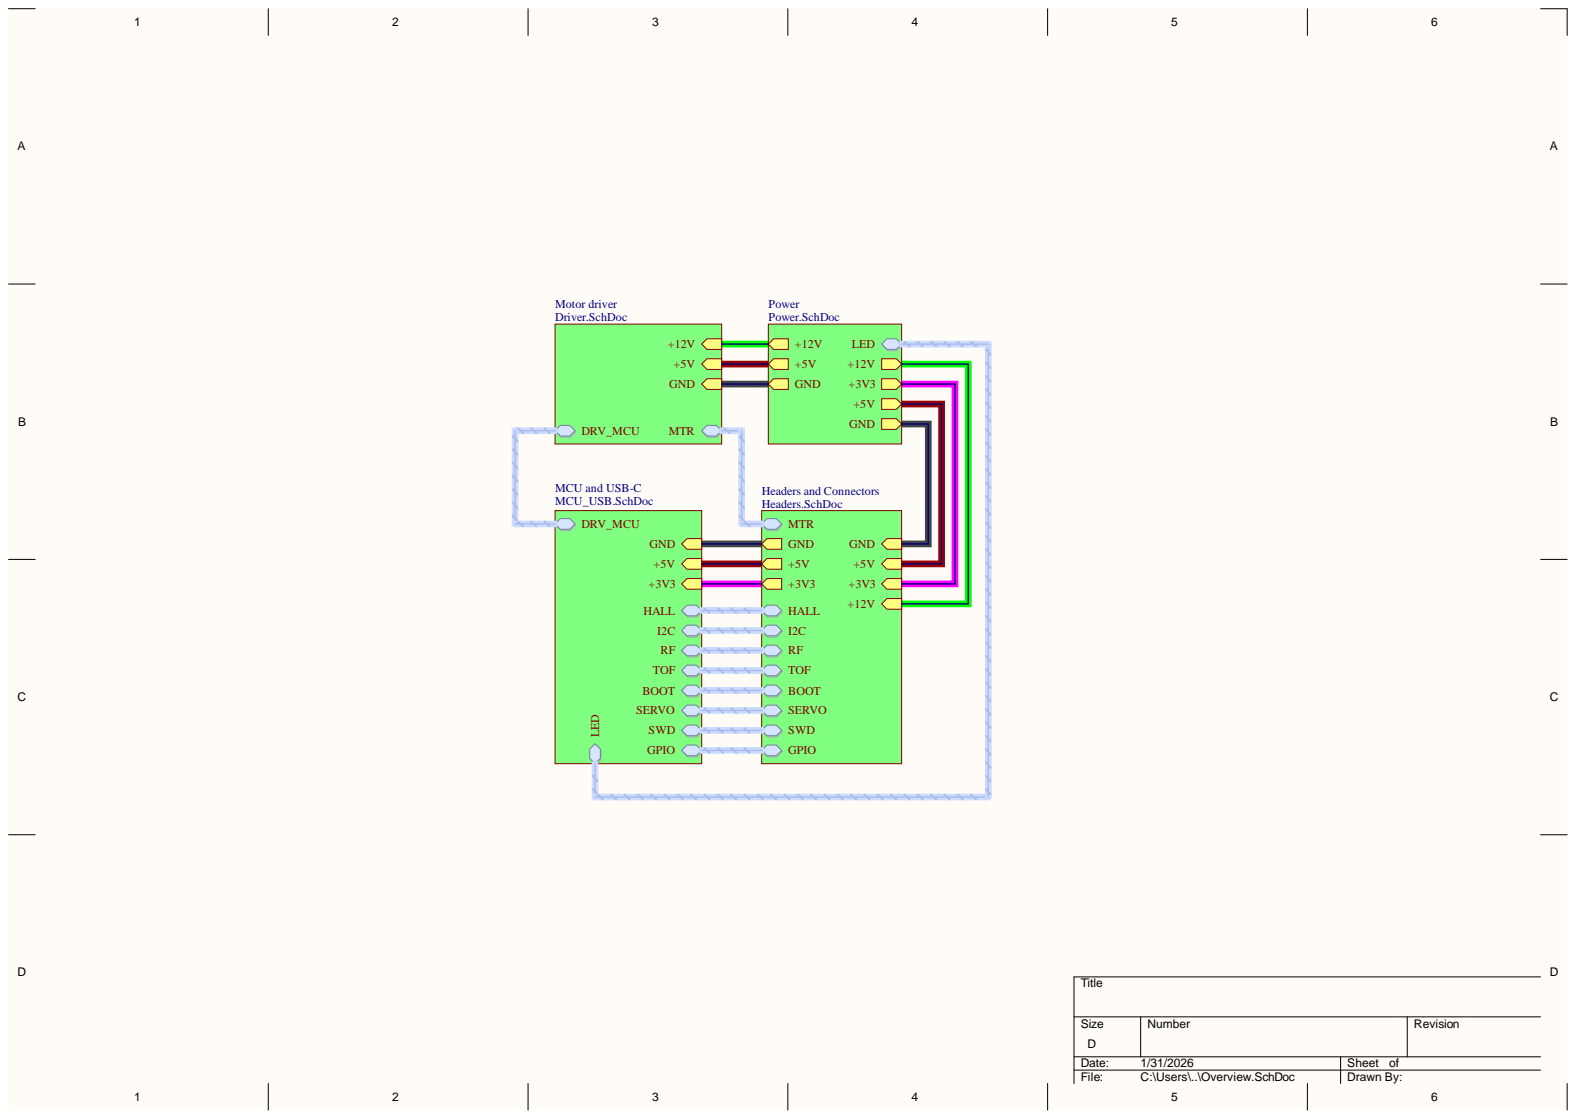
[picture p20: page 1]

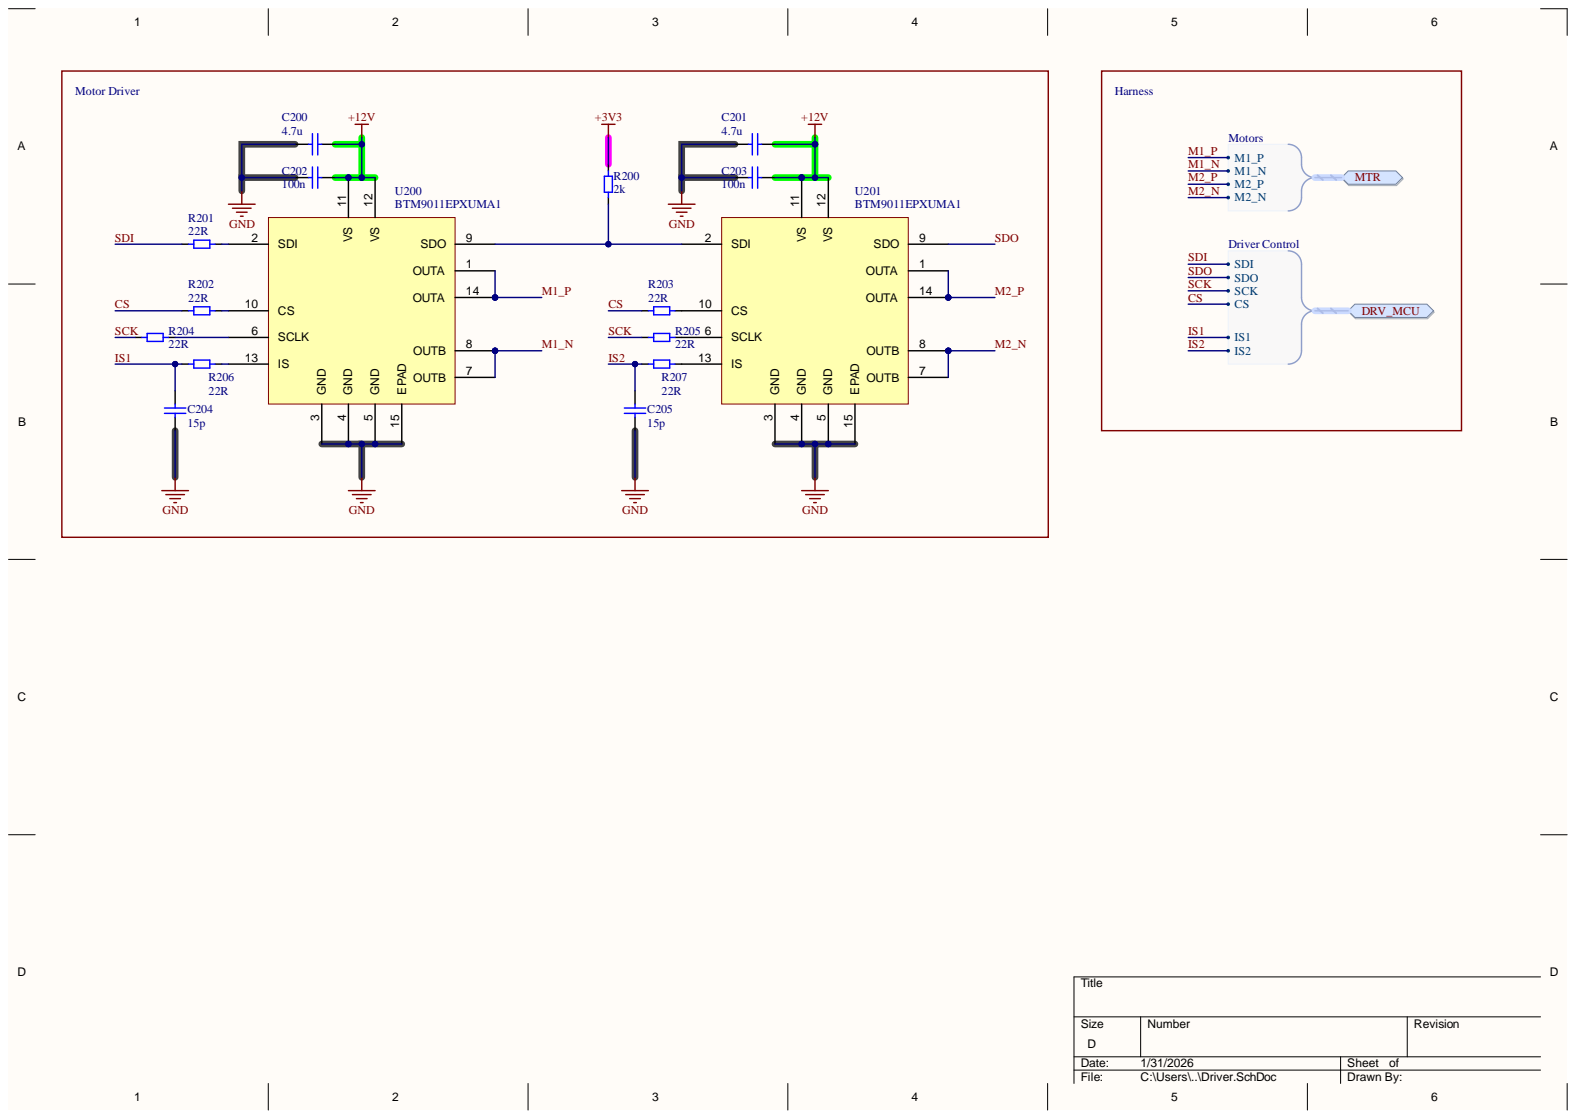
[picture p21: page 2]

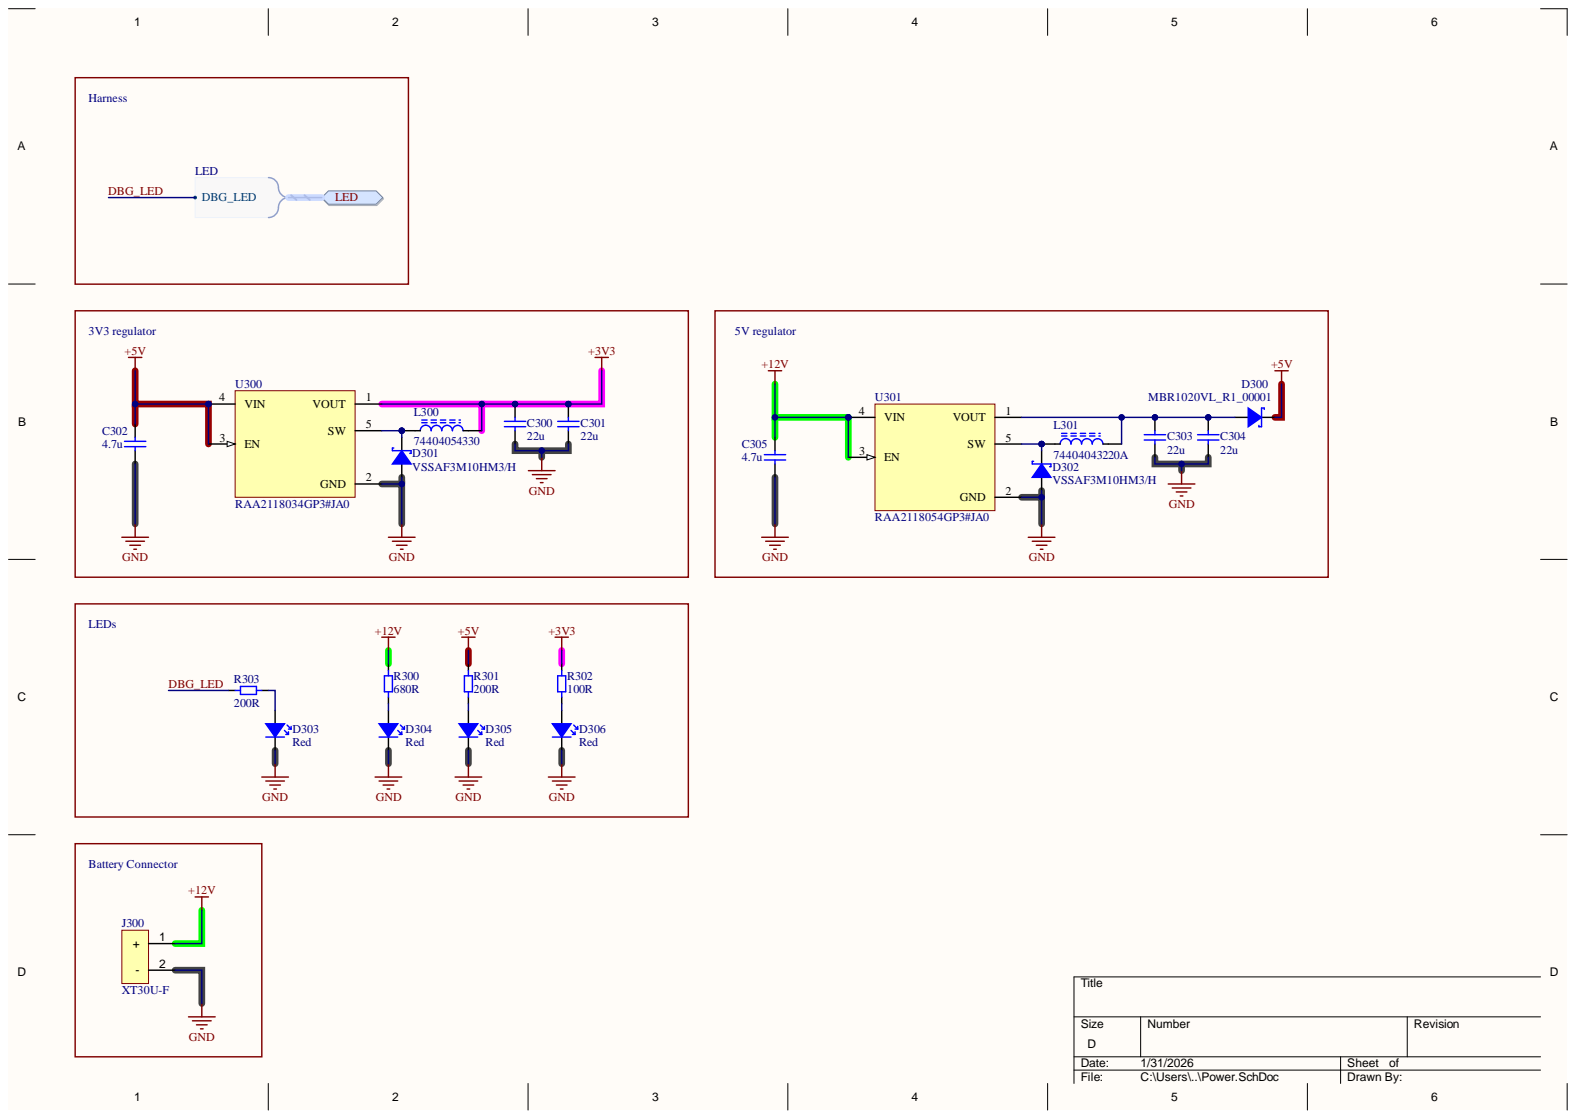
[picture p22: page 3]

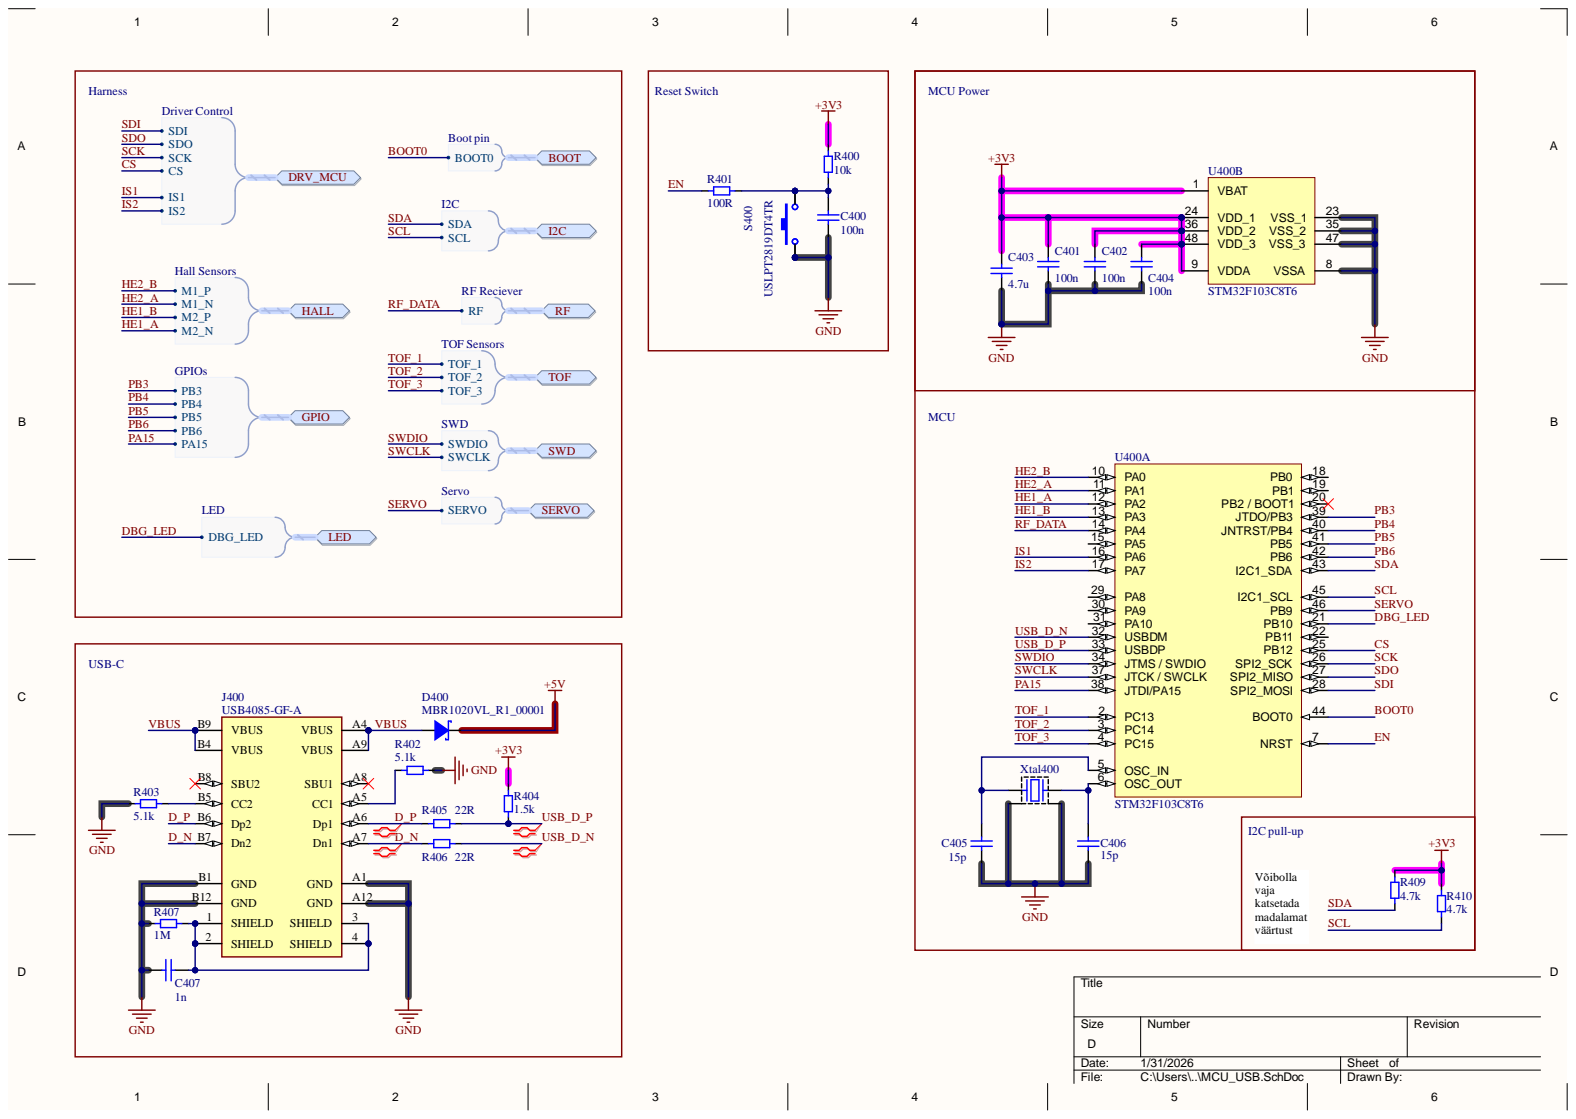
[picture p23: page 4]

vaja katsetada madalamat väärtust

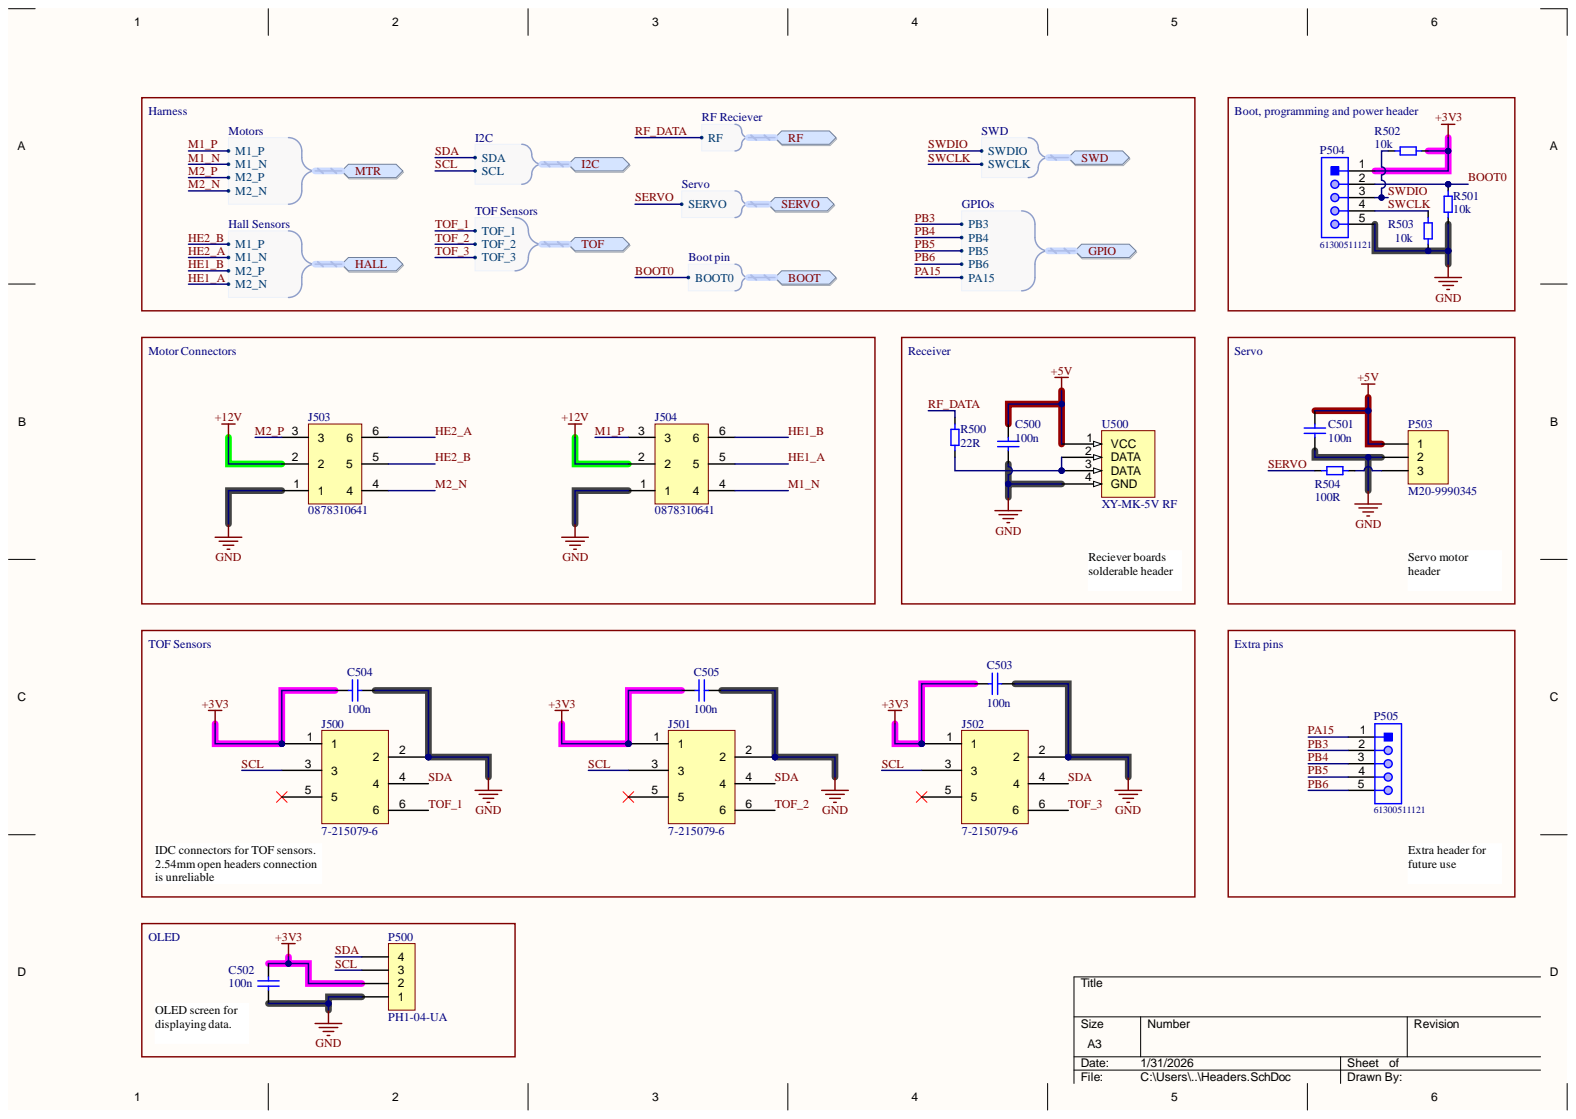
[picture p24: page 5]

Boot, programming and power header

IDC connectors for TOF sensors.
2.54mm open headers connection
is unreliable

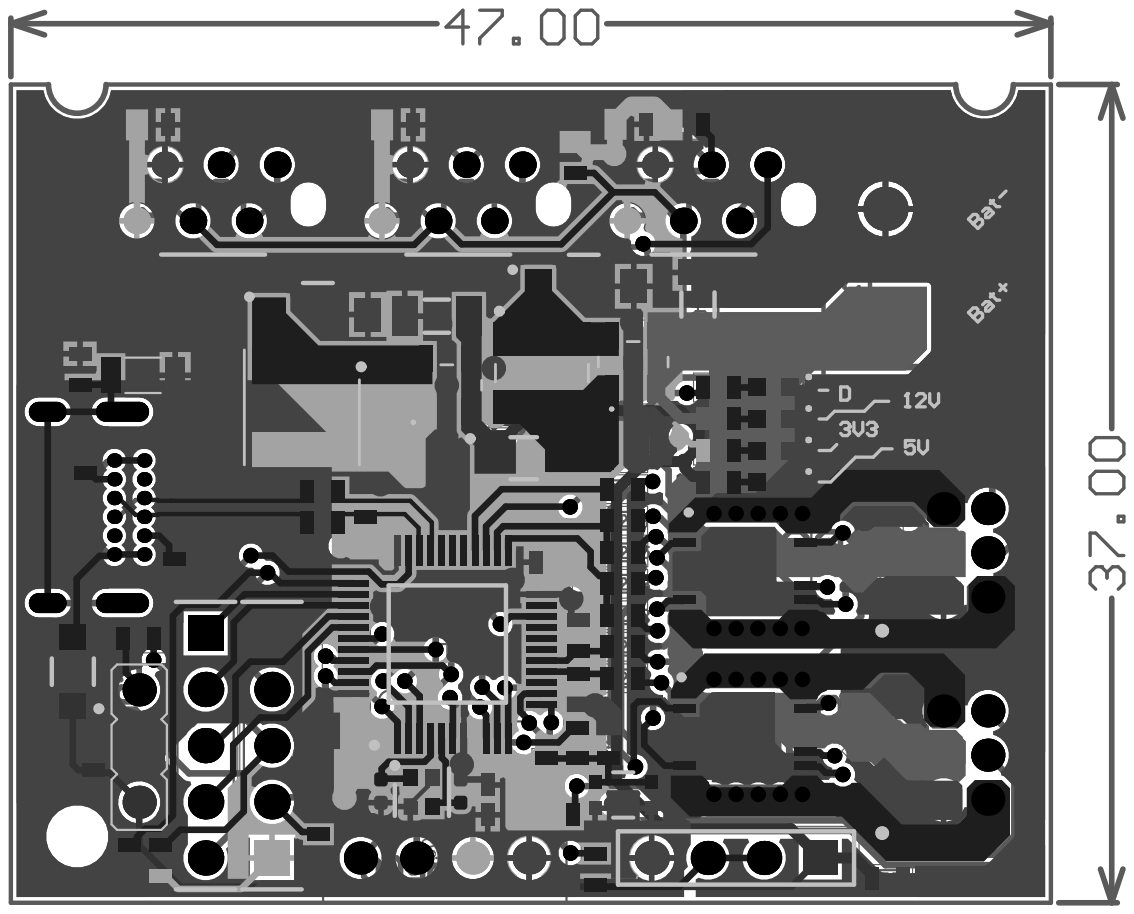
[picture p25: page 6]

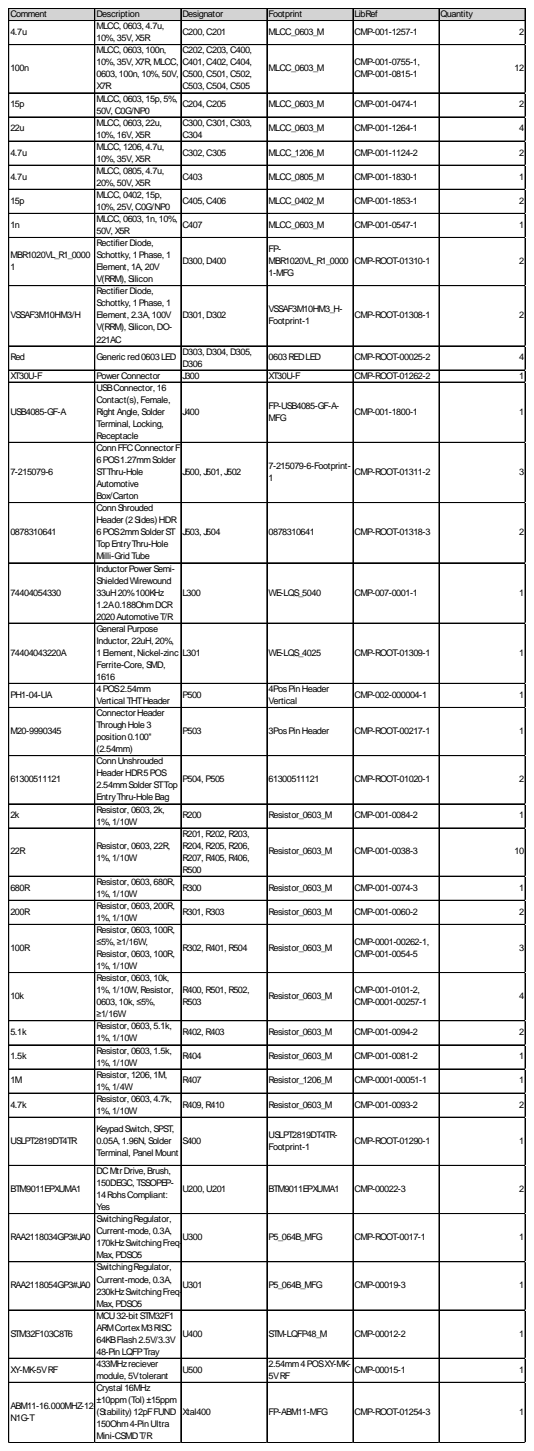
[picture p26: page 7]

Comment | Description | Designator | Footprint | LibRef | Quantity
4.7u | MLCC, 0603, 4.7u, 10%, 35V, X5R | C200, C201 | MLCC_0603_M | CMP-001-1257-1 | 2

100n | MLCC, 0603, 100n, 10%, 35V, X7R, MLCC, 0603, 100n, 10%, 50V, X7R | C202, C203, C400, C401, C402, C404, C500, C501, C502, C503, C504, C505 | MLCC_0603_M | CMP-001-0755-1, CMP-001-0815-1 | 12

15p | MLCC, 0603, 15p, 5%, 50V, C0G/NP0 | C204, C205 | MLCC_0603_M | CMP-001-0474-1 | 2

22u | MLCC, 0603, 22u, 10%, 16V, X5R | C300, C301, C303, C304 | MLCC_0603_M | CMP-001-1264-1 | 4

4.7u | MLCC, 1206, 4.7u, 10%, 35V, X5R | C302, C305 | MLCC_1206_M | CMP-001-1124-2 | 2

4.7u | MLCC, 0805, 4.7u, 20%, 50V, X5R | C403 | MLCC_0805_M | CMP-001-1830-1 | 1

15p | MLCC, 0402, 15p, 10%, 25V, C0G/NP0 | C405, C406 | MLCC_0402_M | CMP-001-1853-1 | 2

1n | MLCC, 0603, 1n, 10%, 50V, X5R | C407 | MLCC_0603_M | CMP-001-0547-1 | 1

MBR1020VL_R1_0000 1 | Rectifier Diode, Schottky, 1Phase, 1 Element, 1A, 20V V(RRM), Silicon | D300, D400 | FP-MBR1020VL_R1_0000 1-MFG | CMP-ROOT-01310-1 | 2

VSSAF3M10HM3/H | Rectifier Diode, Schottky, 1Phase, 1 Element, 2.3A, 100V V(RRM), Silicon, DO-221AC | D301, D302 | VSSAF3M10HM3_H-Footprint-1 | CMP-ROOT-01308-1 | 2

Red | Generic red0603LED | D303, D304, D305, D306 | 0603REDLED | CMP-ROOT-00025-2 | 4

XT30U-F | Power Connector | J300 | XT30U-F | CMP-ROOT-01262-2 | 1
USB4085-GF-A | USBConnector, 16 Contact(s), Female, Right Angle, Solder Terminal, Locking, Receptacle | J400 | FP-USB4085-GF-A-MFG | CMP-001-1800-1 | 1

7-215079-6 | ConnFFCConnector F 6POS1.27mmSolder STThru-Hole Automotive Box/Carton | J500, J501, J502 | 7-215079-6-Footprint-1 | CMP-ROOT-01311-2 | 3

0878310641 | ConnShrouded Header (2Sides) HDR 6POS2mmSolder ST TopEntryThru-Hole Milli-Grid Tube | J503, J504 | 0878310641 | CMP-ROOT-01318-3 | 2

74404054330 | Inductor Power Semi-ShieldedWirewound 33uH20%100KHz 1.2A0.188OhmDCR 2020AutomotiveT/R | L300 | WE-LQS_5040 | CMP-007-0001-1 | 1

74404043220A | General Purpose Inductor, 22uH, 20%, 1Element, Nickel-zinc Ferrite-Core, SMD, 1616 | L301 | WE-LQS_4025 | CMP-ROOT-01309-1 | 1

PH1-04-UA | 4POS2.54mm Vertical THTHeader | P500 | 4PosPin Header Vertical | CMP-002-000004-1 | 1

M20-9990345 | Connector Header ThroughHole 3 position0.100" (2.54mm) | P503 | 3PosPin Header | CMP-ROOT-00217-1 | 1

61300511121 | ConnUnshrouded Header HDR5POS 2.54mmSolder STTop EntryThru-HoleBag | P504, P505 | 61300511121 | CMP-ROOT-01020-1 | 2

2k | Resistor, 0603, 2k, 1%, 1/10W | R200 | Resistor_0603_M | CMP-001-0084-2 | 1

22R | Resistor, 0603, 22R, 1%, 1/10W | R201, R202, R203, R204, R205, R206, R207, R405, R406, R500 | Resistor_0603_M | CMP-001-0038-3 | 10

680R | Resistor, 0603, 680R, 1%, 1/10W | R300 | Resistor_0603_M | CMP-001-0074-3 | 1

200R | Resistor, 0603, 200R, 1%, 1/10W | R301, R303 | Resistor_0603_M | CMP-001-0060-2 | 2

100R | Resistor, 0603, 100R, ≤5%, ≥1/16W, Resistor, 0603, 100R, 1%, 1/10W | R302, R401, R504 | Resistor_0603_M | CMP-0001-00262-1, CMP-001-0054-5 | 3

10k | Resistor, 0603, 10k, 1%, 1/10W, Resistor, 0603, 10k, ≤5%, ≥1/16W | R400, R501, R502, R503 | Resistor_0603_M | CMP-001-0101-2, CMP-0001-00257-1 | 4

5.1k | Resistor, 0603, 5.1k, 1%, 1/10W | R402, R403 | Resistor_0603_M | CMP-001-0094-2 | 2

1.5k | Resistor, 0603, 1.5k, 1%, 1/10W | R404 | Resistor_0603_M | CMP-001-0081-2 | 1

1M | Resistor, 1206, 1M, 1%, 1/4W | R407 | Resistor_1206_M | CMP-0001-00051-1 | 1

4.7k | Resistor, 0603, 4.7k, 1%, 1/10W | R409, R410 | Resistor_0603_M | CMP-001-0093-2 | 2

USLPT2819DT4TR | KeypadSwitch, SPST, 0.05A, 1.96N, Solder Terminal, Panel Mount | S400 | USLPT2819DT4TR-Footprint-1 | CMP-ROOT-01290-1 | 1

BTM9011EPXUMA1 | DCMtr Drive, Brush, 150DEGC, TSSOPEP-14RohsCompliant: Yes | U200, U201 | BTM9011EPXUMA1 | CMP-00022-3 | 2

RAA2118034GP3#JA0 | SwitchingRegulator, Current-mode, 0.3A, 170kHzSwitchingFreq-Max, PDSO5 | U300 | P5_064B_MFG | CMP-ROOT-0017-1 | 1

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

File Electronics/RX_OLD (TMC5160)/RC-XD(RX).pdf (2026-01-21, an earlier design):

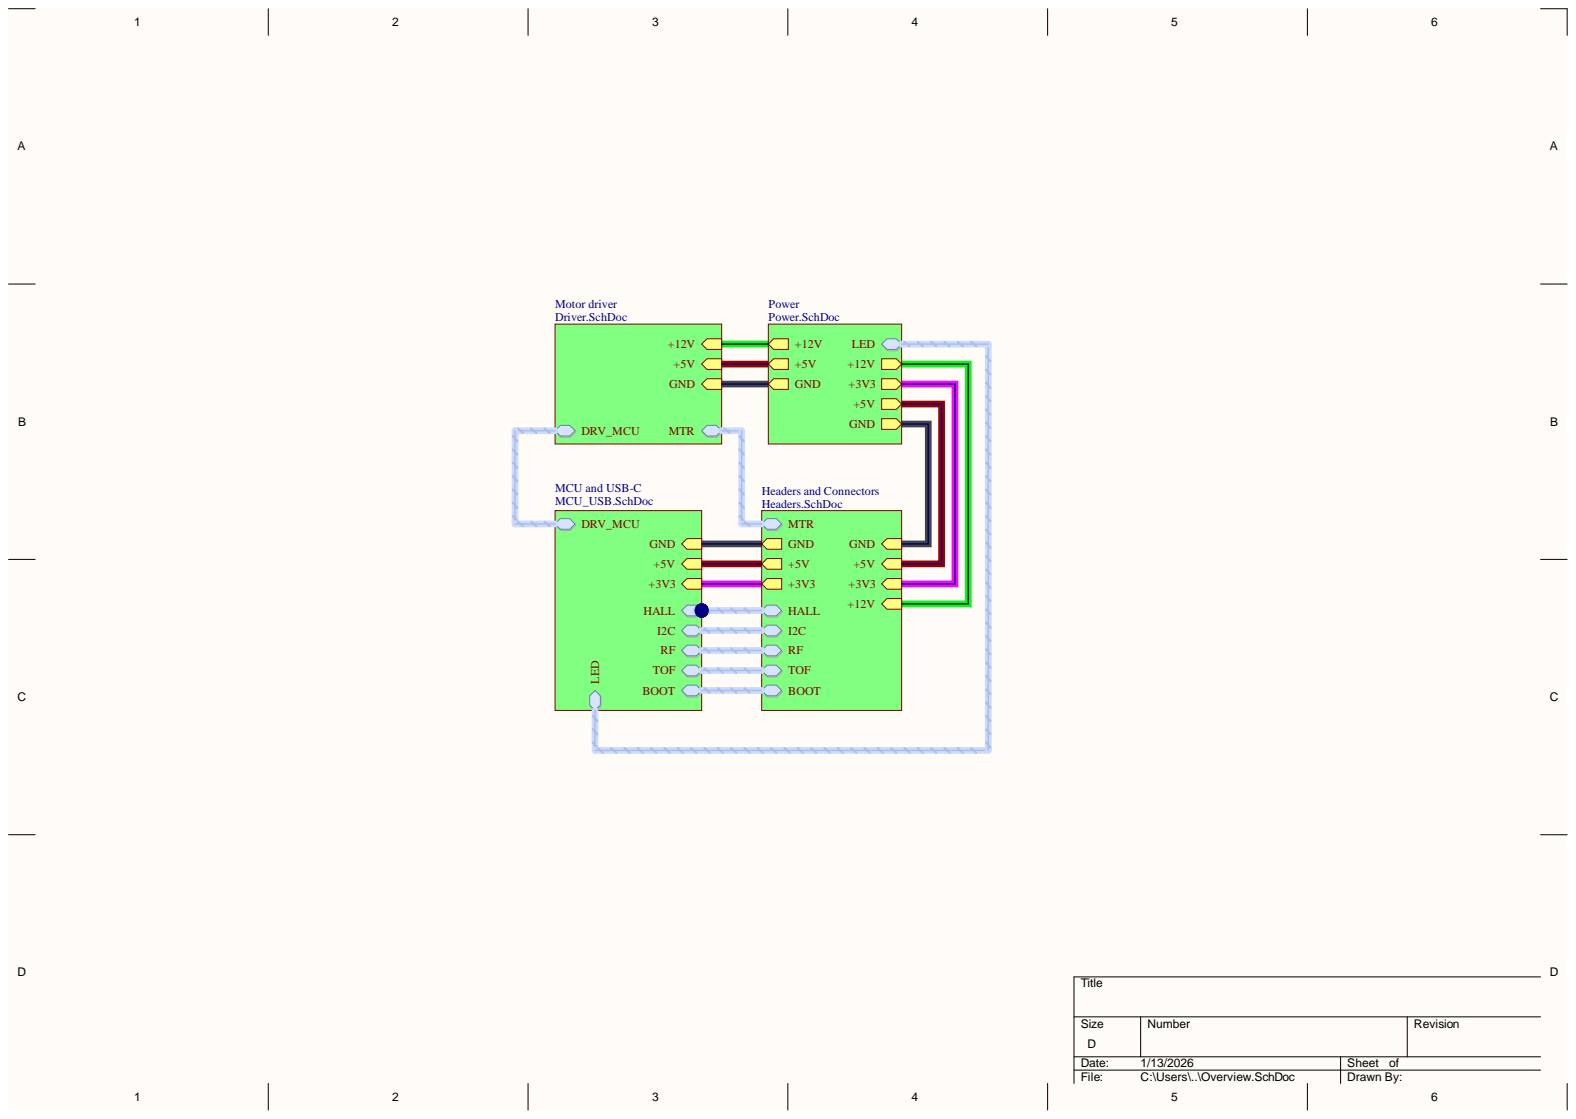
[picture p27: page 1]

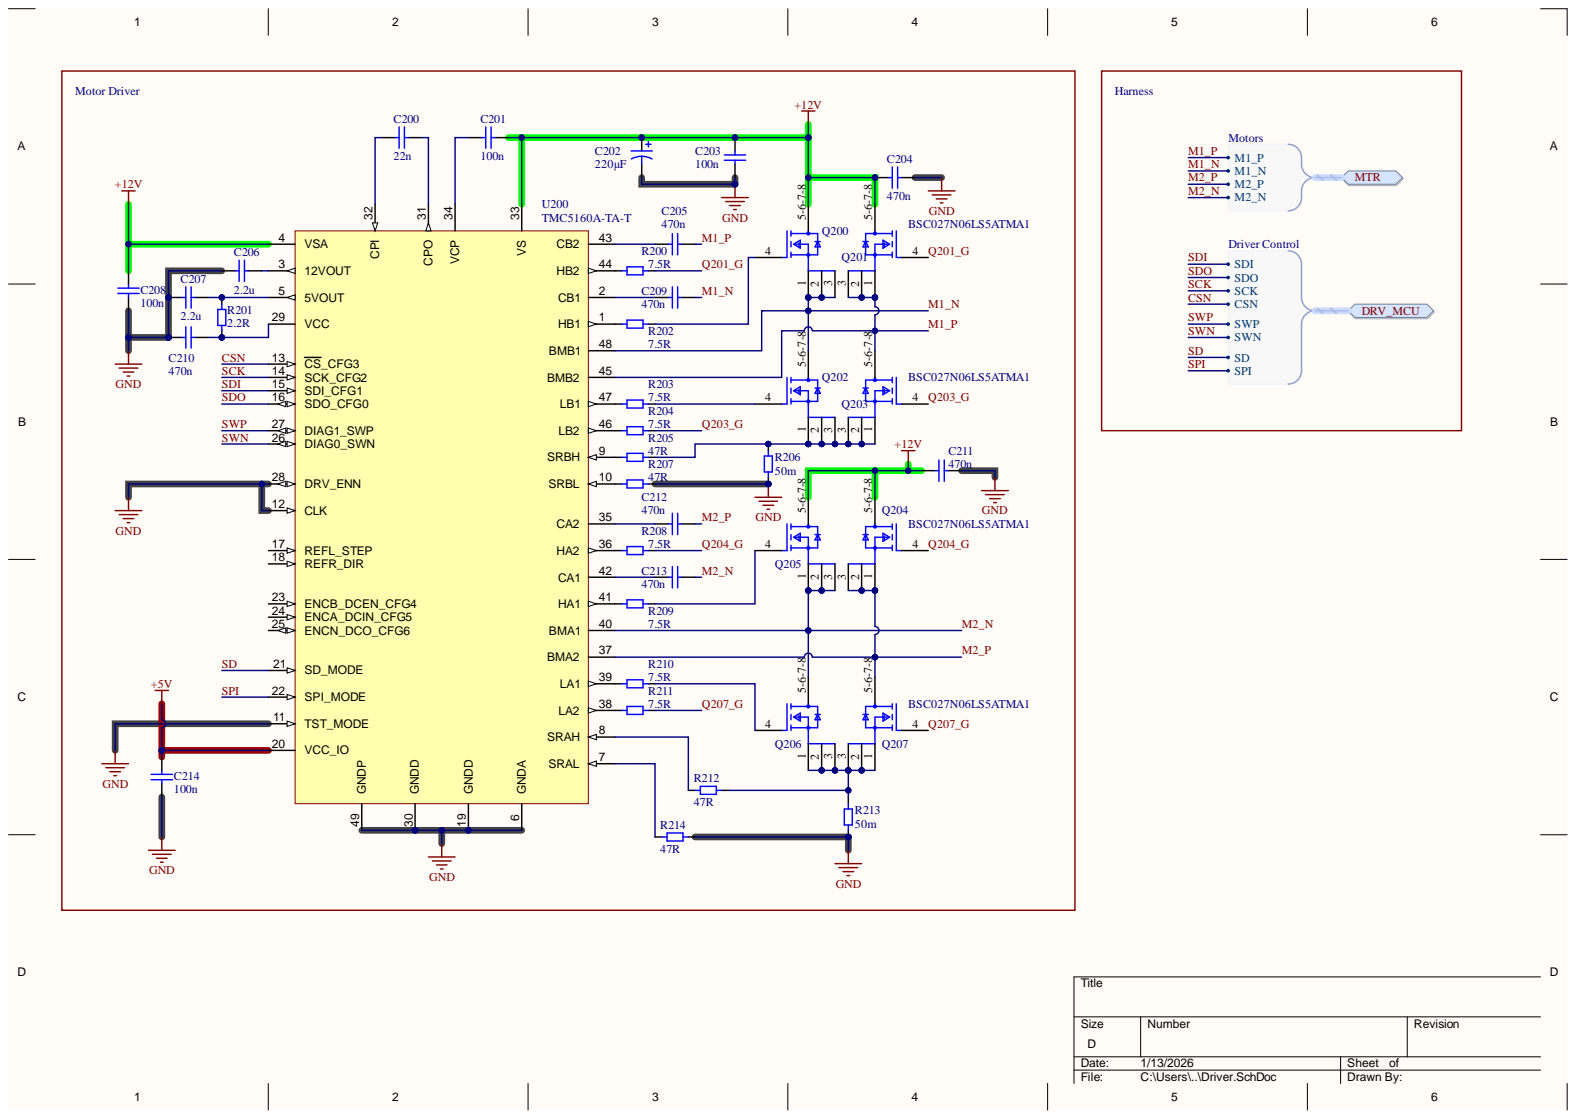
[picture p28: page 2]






22n | MLCC, 0603, 22n, 10%, 6.3V, X7R | C200 | MLCC_0603_M | CMP-001-0577-1 | 1

100n | MLCC, 0603, 100n, 10%, 35V, X7R, MLCC, 0603, 100n, 10%, 50V, X7R | C201, C203, C208, C214, C400, C401, C403, C404 | MLCC_0603_M | CMP-001-0755-1, CMP-001-0815-1 | 8

EEU-FS1H221L | Panasonic EEUFS1H221L-AluminumElectrolytic Capacitors (Radial LeadType) | C202 | 8mmCap | CMP-002-0010-1 | 1

470n | MLCC, 0805, 470n, 10%, 6.3V, X7R | C204, C205, C209, C210, C211, C212, C213 | MLCC_0805_M | CMP-001-0836-2 | 7

2.2u | MLCC, 0805, 2.2u, 10%, 6.3V, X7R | C206, C207 | MLCC_0805_M | CMP-001-0842-2 | 2

22u | MLCC, 0603, 22u, 10%, 16V, X5R | C300, C301, C302, C303 | MLCC_0603_M | CMP-001-1264-1 | 4

4.7u | MLCC, 1206, 4.7u, 10%, 35V, X5R | C304, C306 | MLCC_1206_M | CMP-001-1124-2 | 2

4.7u | MLCC, 0805, 4.7u, 20%, 50V, X5R | C402 | MLCC_0805_M | CMP-001-1830-1 | 1

15p | MLCC, 0402, 15p, 10%, 25V, C0G/NP0 | C405, C406 | MLCC_0402_M | CMP-001-1853-1 | 2

1n | MLCC, 0603, 1n, 10%, 50V, X5R | C407 | MLCC_0603_M | CMP-001-0547-1 | 1

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

VSSAF3M10HM3/H | Rectifier Diode, Schottky, 1Phase, 1 Element, 2.3A, 100V V(RRM), Silicon, DO-221AC | D301, D310 | VSSAF3M10HM3_H-Footprint-1 | CMP-ROOT-01308-1 | 2

Clear | LEDUni-Color Cool White2-Pin T-13/4 Ammo | D302, D303, D308, D309 | C503D-WAN-CCBEB152-Footprint-1 | CMP-00017-1 | 4

Red | Generic red0603LED | D304, D305, D306, D307 | 0603REDLED | CMP-ROOT-00025-2 | 4

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

S2B-PH-K-S(LF)(SN) | ConnShrouded Header (4Sides) HDR 2POS2mmSolder RA Thru-HoleBox | P300 | B5B-PH-K-S(LF)(SN) | CMP-ROOT-00728-2 | 1

M20-9990345 | Connector Header ThroughHole 3 position0.100" (2.54mm) | P400 | 3PosPin Header | CMP-ROOT-00217-1 | 1

PH1-04-UA | 4POS2.54mm Vertical THTHeader | P500 | 4PosPin Header Vertical | CMP-002-000004-1 | 1

B6B-ZR(LF)(SN) | Header for PCB; pitch 1.50mm; 6-contacts; THT; male; topentry; 50V/1A | P502, P503 | FP-B6B-ZR-SM4-TF_LF_SN-MFG | CMP-ROOT-01270-2 | 2

BSC027N06LS5ATMA1 | Power MOSFET, N Channel, 60V, 100A, 0.0027ohm, TDSON, Surface Mount | Q200, Q201, Q202, Q203, Q204, Q205, Q206, Q207 | FP-PG-TDSON-8-MFG | CMP-ROOT-01287-1 | 8

BSS84-7-F | Transistor: P-MOSFET; unipolar; -50V; -130mA; 10ohm; 300mW; -55+150 deg.C; SMD; SOT23 | Q300 | SOT-23-3 | CMP-ROOT-01301-1 | 1

MMBT3904-TP | TRANSNPN40V0.2A SOT23 | Q301 | SOT-23-3 | CMP-ROOT-00274-1 | 1

7.5R | Resistor, 0603, 7.5R, 1%, 1/10W | R200, R202, R203, R204, R208, R209, R210, R211 | Resistor_0603_M | CMP-001-0026-2 | 8

2.2R | Resistor, 0603, 2.2R, 1%, 1/10W | R201 | Resistor_0603_M | CMP-001-0012-2 | 1

47R | Resistor, 0603, 47R, 1%, 1/10W | R205, R207, R212, R214 | Resistor_0603_M | CMP-001-0046-3 | 4

PE0612FKM7W0R05L | Current Sensor-Low TCRChip Resistor WideTerminal Metal Alloy061250mOhm 1%EmbossT/R | R206, R213 | PE0612FKM7W0R05L-Footprint-1 | CMP-001-1896-1 | 2

36R | Resistor, 0603, 36R, 1%, 1/10W | R302, R309, R311, R313 | Resistor_0603_M | CMP-001-0043-3 | 4

10k | Resistor, 0603, 10k, 1%, 1/10W | R303, R401 | Resistor_0603_M | CMP-001-0101-2 | 2

3k | Resistor, 0603, 3k, 1%, 1/10W | R304 | Resistor_0603_M | CMP-001-0088-2 | 1

200R | Resistor, 0603, 200R, 1%, 1/10W | R305, R306, R307, R308 | Resistor_0603_M | CMP-001-0060-2 | 4

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

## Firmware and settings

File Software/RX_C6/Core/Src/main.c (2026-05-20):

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
/* Includes ------------------------------------------------------------------*/
#include "main.h"

/* USER CODE BEGIN Includes */
#include "btm9011_simple.h"
#include "ibus.h"
/* USER CODE END Includes */

/* USER CODE BEGIN PD */

// PWM täiteteguri samm
#define MOTOR_PWM_STEPS 32U

// Mootorie miinimum täitetegur
#define MOTOR_DUTY_MIN  2U

// Maksimaalne lubatud servo pööramise samm
#define SERVO_MAX_STEP  25U

/* USER CODE END PD */

SPI_HandleTypeDef hspi1;

TIM_HandleTypeDef htim2;
TIM_HandleTypeDef htim3;

UART_HandleTypeDef huart1;
DMA_HandleTypeDef hdma_usart1_rx;

/* USER CODE BEGIN PV */

// iBus safe hoiab kõiki puldi kanali väärtusi
static uint16_t  ibus_safe[IBUS_USER_CHANNELS] = {0};
// Servo positsiooni muutuja, keskpunktis alustab
volatile uint16_t g_servo_pos = 1500;

/* USER CODE END PV */


void SystemClock_Config(void);
static void MX_GPIO_Init(void);
static void MX_DMA_Init(void);
static void MX_SPI1_Init(void);
static void MX_USART1_UART_Init(void);
static void MX_TIM2_Init(void);
static void MX_TIM3_Init(void);
/**
  * @brief  The application entry point.
  * @retval int
  */
int main(void)
{

  /* MCU Configuration--------------------------------------------------------*/

  HAL_Init();

  /* Configure the system clock */
  SystemClock_Config();

  /* Initialize all configured peripherals */
  MX_GPIO_Init();
  MX_DMA_Init();
  MX_SPI1_Init();
  MX_USART1_UART_Init();
  MX_TIM2_Init();
  MX_TIM3_Init();
  /* USER CODE BEGIN 2 */

  // Aktiive nullolekuga LED, algselt HIGH, et oleks kustu
  HAL_GPIO_WritePin(DBG_LED_GPIO_Port, DBG_LED_Pin, GPIO_PIN_SET);

  // Mootorite juhtkiibid on kaskaadühenduses kasutades SPI1 ja CS_Pin
  btm_init(&hspi1, CS_GPIO_Port, CS_Pin);

  // Mõlemad mootorid alustavad seiskuna
  btm_brake();

  /* Servo - kasutab TIM3, mis teeb takti ette PWM jaoks
   * Vasak - 1000
   * Kesk - 1500
   * Parem - 3000
  */
  HAL_TIM_PWM_Start(&htim3, TIM_CHANNEL_2);
  __HAL_TIM_SET_COMPARE(&htim3, TIM_CHANNEL_2, 1500);

  // iBus saadab infot PB7 pinnil läbi USART1
  ibus_init();

  /* USER CODE END 2 */

  /* Infinite loop */
  /* USER CODE BEGIN WHILE */

  uint8_t  pwm_count = 0;			// PWM täiteteguri samm
  uint8_t  dir       = BTM_BRAKE;	// Mootorite suund
  uint8_t  duty      = 0;			// Täitetegur

  while (1)
  {
    /* USER CODE END WHILE */

    /* USER CODE BEGIN 3 */

    // Lukustus - kanal 7 (SWA): all = lukus, üleval = sõit lubatud
    if (ibus_safe[6] < 1500) {
      dir  = BTM_BRAKE;
      duty = 0;
    } else {
      // Mootori kiirus ja suund - parem kangi vertikaalne telg (kanal 2)
      // Kesk ~1500 = pidurdus, üles > 1550 = edasi, alla < 1450 = tagurpidi
      uint16_t raw = ibus_safe[1];
      if (raw < 1000) raw = 1000;
      if (raw > 2000) raw = 2000;

      if (raw > 1550) {
        uint16_t mag = raw - 1500;
        duty = MOTOR_DUTY_MIN + (uint8_t)(mag * (MOTOR_PWM_STEPS - MOTOR_DUTY_MIN) / 500);
        dir  = BTM_REVERSE;
      } else if (raw < 1450) {
        uint16_t mag = 1500 - raw;
        duty = MOTOR_DUTY_MIN + (uint8_t)(mag * (MOTOR_PWM_STEPS - MOTOR_DUTY_MIN) / 500);
        dir  = BTM_FORWARD;
      } else {
        dir  = BTM_BRAKE;
        duty = 0;
      }
    }

    if (dir == BTM_BRAKE || pwm_count >= duty)
      btm_brake();
    else
      btm_drive(dir, dir);
    if (++pwm_count >= MOTOR_PWM_STEPS) pwm_count = 0;

  }
  /* USER CODE END 3 */
}

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
/* USER CODE BEGIN 4 */

/* TIM2 fires at 16 000 Hz — feeds the RF433 bit-sampling state machine
void HAL_TIM_PeriodElapsedCallback(TIM_HandleTypeDef *htim)
{
  if (htim->Instance == TIM2)
    RF433_TimerISR(&hrf);
}*/

void HAL_UART_RxCpltCallback(UART_HandleTypeDef *huart)
{
	// Võrdleb kas sisse tulev UART info on USART1 või mitte
	// Kui ei ole lõpetab Callbacki
  if (huart->Instance != USART1) return;

  /* Alustab uuesti failsafe lugejat
   * kui mingi ajatagant ei saa infot paneb kõik kinni
   *
   * iBus read täidab seda muutujat uuesti */
  ibus_reset_failsafe();
  ibus_read(ibus_safe);

  // Lukustus - kui kanal 7 all, servo ei reageeri
  if (ibus_safe[6] < 1500) return;

  // Servomootoriga pööramine - vasak kangi horisontaalne telg (kanal 4)
  uint16_t servo_target = ibus_safe[3];
  // Min ja Max piiramine
  if (servo_target < 1000) servo_target = 1000;
  if (servo_target > 2000) servo_target = 2000;

  // Pööramine on tagurpidi, see pöörab tagasi
  servo_target = 3000 - servo_target;
  /* Piirab pööramis kiirust, kui liiga äkiline liigutus
   * tõmbab liiga palju voolu ja lükkab MCU imelikku oleku
   * kus kõik lõpetab töötamise */
  if      (servo_target > g_servo_pos + SERVO_MAX_STEP) g_servo_pos += SERVO_MAX_STEP;
  else if (servo_target + SERVO_MAX_STEP < g_servo_pos) g_servo_pos -= SERVO_MAX_STEP;
  else                                                  g_servo_pos  = servo_target;
  // Määrab lõpuks servomootori nurga
  __HAL_TIM_SET_COMPARE(&htim3, TIM_CHANNEL_2, g_servo_pos);
}

/* USER CODE END 4 */
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


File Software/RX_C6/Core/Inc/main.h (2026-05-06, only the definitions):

#define TOF_1_Pin GPIO_PIN_13
#define TOF_1_GPIO_Port GPIOC
#define TOF_2_Pin GPIO_PIN_14
#define TOF_2_GPIO_Port GPIOC
#define TOF_3_Pin GPIO_PIN_15
#define TOF_3_GPIO_Port GPIOC
#define HE2_B_Pin GPIO_PIN_0
#define HE2_B_GPIO_Port GPIOA
#define HE2_A_Pin GPIO_PIN_1
#define HE2_A_GPIO_Port GPIOA
#define HE1_B_Pin GPIO_PIN_2
#define HE1_B_GPIO_Port GPIOA
#define RF_DATA_Pin GPIO_PIN_3
#define RF_DATA_GPIO_Port GPIOA
#define HE1_A_Pin GPIO_PIN_4
#define HE1_A_GPIO_Port GPIOA
#define IS1_Pin GPIO_PIN_0
#define IS1_GPIO_Port GPIOB
#define IS2_Pin GPIO_PIN_1
#define IS2_GPIO_Port GPIOB
#define DBG_LED_Pin GPIO_PIN_10
#define DBG_LED_GPIO_Port GPIOB
#define CS_Pin GPIO_PIN_12
#define CS_GPIO_Port GPIOB
#define PA15_Pin GPIO_PIN_15
#define PA15_GPIO_Port GPIOA
#define PB3_Pin GPIO_PIN_3
#define PB3_GPIO_Port GPIOB
#define PB4_Pin GPIO_PIN_4
#define PB4_GPIO_Port GPIOB
#define PB8_Pin GPIO_PIN_8
#define PB8_GPIO_Port GPIOB
#define SERVO_Pin GPIO_PIN_9
#define SERVO_GPIO_Port GPIOB

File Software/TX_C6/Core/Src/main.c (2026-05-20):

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
/* Includes ------------------------------------------------------------------*/
#include "main.h"

/* USER CODE BEGIN Includes */
#include "ask_hal.h"
/* USER CODE END Includes */

/* USER CODE BEGIN PD */

#define JOY_CENTER    2048                                          /* ADC mid-scale */
#define JOY_DEADZONE  200                                           /* dead-band either side */
#define JOY_RANGE     (JOY_CENTER - JOY_DEADZONE)                  /* usable range: 1848 */
#define MOTOR_DUTY_MIN  2U                                          /* min duty when moving */
#define MOTOR_DUTY_MAX  31U                                         /* matches MOTOR_PWM_STEPS-1 on RX */

/* Packet field: direction byte values — must match btm9011_simple.h on RX */
#define DIR_BRAKE    0U
#define DIR_FORWARD  1U
#define DIR_REVERSE  2U

/* ASK transmission parameters */
#define ASK_BIT_TIME_US  1000U   /* 1 kbps — conservative, suits XY-MK-5V/FS1000A */
#define ASK_RETRIES      2U      /* repeat count per ask_send_bytes call */
#define ASK_SEND_PERIOD  50U     /* ms between transmissions (~20 Hz update rate) */

/* USER CODE END PD */

ADC_HandleTypeDef hadc1;

I2C_HandleTypeDef hi2c1;

TIM_HandleTypeDef htim2;

void SystemClock_Config(void);
static void MX_GPIO_Init(void);
static void MX_I2C1_Init(void);
static void MX_TIM2_Init(void);
static void MX_ADC1_Init(void);
/* USER CODE BEGIN PFP */

static uint16_t ADC_ReadChannel(uint32_t channel);

/* USER CODE END PFP */

/**
  * @brief  The application entry point.
  * @retval int
  */
int main(void)
{

  /* MCU Configuration--------------------------------------------------------*/

  /* Reset of all peripherals, Initializes the Flash interface and the Systick. */
  HAL_Init();

  /* Configure the system clock */
  SystemClock_Config();

  /* Initialize all configured peripherals */
  MX_GPIO_Init();
  MX_I2C1_Init();
  MX_TIM2_Init();
  MX_ADC1_Init();
  /* USER CODE BEGIN 2 */

  /* ASK 433 MHz transmitter — TX-only, no RX pin on this board */
  ask433.fn_micros    = ask_micros_433;
  ask433.fn_delay_ms  = ask_delay_ms_433;
  ask433.fn_delay_us  = ask_delay_us_433;
  ask433.fn_init_tx   = ask_init_tx433;
  ask433.fn_write_pin = ask_write_pin_433;
  ask433.fn_init_rx   = NULL;
  ask433.fn_read_pin  = NULL;
  ask_init(&ask433);

  /* USER CODE END 2 */

  /* Infinite loop */
  /* USER CODE BEGIN WHILE */

  while (1)
  {
    /* USER CODE END WHILE */

    /* USER CODE BEGIN 3 */

    /* Read joystick axes */
    uint16_t raw_v = ADC_ReadChannel(ADC_CHANNEL_0); /* vertical  — throttle */
    uint16_t raw_h = ADC_ReadChannel(ADC_CHANNEL_1); /* horizontal — steering */

    /* ── Throttle ─────────────────────────────────────────────────────────── */
    int16_t  dv       = (int16_t)raw_v - JOY_CENTER;
    uint8_t  duty     = 0;
    uint8_t  dir      = DIR_BRAKE;

    if (dv > (int16_t)JOY_DEADZONE) {
      int16_t mag = dv - (int16_t)JOY_DEADZONE;
      if (mag > (int16_t)JOY_RANGE) mag = (int16_t)JOY_RANGE;
      duty = (uint8_t)(MOTOR_DUTY_MIN + (uint32_t)mag * (MOTOR_DUTY_MAX - MOTOR_DUTY_MIN) / JOY_RANGE);
      dir  = DIR_FORWARD;
    } else if (dv < -(int16_t)JOY_DEADZONE) {
      int16_t mag = -dv - (int16_t)JOY_DEADZONE;
      if (mag > (int16_t)JOY_RANGE) mag = (int16_t)JOY_RANGE;
      duty = (uint8_t)(MOTOR_DUTY_MIN + (uint32_t)mag * (MOTOR_DUTY_MAX - MOTOR_DUTY_MIN) / JOY_RANGE);
      dir  = DIR_REVERSE;
    }

    /* ── Steering ─────────────────────────────────────────────────────────── */
    /* Map 0-4095 → 0-255 */
    uint8_t steering = (uint8_t)(raw_h * 255U / 4095U);

    /* ── Build and send 3-byte packet ────────────────────────────────────── */
    /* [duty 0-31][dir 0=brake/1=fwd/2=rev][steering 0-255, 128=centre] */
    uint8_t pkt[3] = { duty, dir, steering };
    ask_send_bytes(&ask433, pkt, 3, ASK_BIT_TIME_US, ASK_RETRIES);

    HAL_Delay(ASK_SEND_PERIOD);

    /* USER CODE END 3 */
  }
}

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
/* USER CODE BEGIN 4 */

static uint16_t ADC_ReadChannel(uint32_t channel)
{
    ADC_ChannelConfTypeDef sConfig = {0};
    sConfig.Channel      = channel;
    sConfig.Rank         = ADC_REGULAR_RANK_1;
    sConfig.SamplingTime = ADC_SAMPLETIME_1CYCLE_5;
    HAL_ADC_ConfigChannel(&hadc1, &sConfig);
    HAL_ADC_Start(&hadc1);
    HAL_ADC_PollForConversion(&hadc1, 10);
    uint16_t val = (uint16_t)HAL_ADC_GetValue(&hadc1);
    HAL_ADC_Stop(&hadc1);
    return val;
}

/* USER CODE END 4 */
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


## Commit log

2026-01-21 Combining of two projects
    [Driver.SchDoc, RC-XD(TX).PrjPcb, TX.PcbDoc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]
2026-01-21 Combining of branches v2
    [Headers.SchDoc, MCU_USB.SchDoc, Overview.SchDoc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]
2026-01-23 ReadMe update regarding 24/1/25, also need to make seperate branches
    [Driver.SchDoc, Headers.SchDoc, MCU_USB.SchDoc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]
2026-01-24 New update, TX got full new redesign and old is saved at preIDC folder
    [RC-XD(TX).PrjPcb, TX.PcbDoc, TX.SchDoc]
2026-01-26 Both RX and TX new designs pass DRC with 0 errors and waives
    [Driver.SchDoc, Overview.SchDoc, TX.SchDoc]
2026-01-26 Parameter update ja STEP export
    [RC-XD(RX).PrjPcb, TX.SchDoc]
2026-01-26 Seperate folders, ReadMes and better hiearchy
    [Driver.SchDoc, Headers.SchDoc, MCU_USB.SchDoc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]
2026-01-30 Finished Rev1.2 or smth, docs will be updated later
    [Headers.SchDoc, MCU_USB.SchDoc, Overview.SchDoc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]
2026-01-30 2nd review done, pcb order now
    [Headers.SchDoc, MCU_USB.SchDoc, RX.PcbDoc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]
2026-01-30 Panelized TX correctly, ready to order
    [TX.PcbDoc, TX.SchDoc]
2026-03-25 v1 of RX ordered, readMe updated
    [RC-XD(RX).PrjPcb, RC-XD(RX).xlsx, RX.PcbDoc]
2026-04-11 PDF v1
    [RC-XD(RX).PrjPcb, RX.PcbDoc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]
2026-05-06 Working v0 before changing to simpler btm9011 library
    [MCU_USB.SchDoc, Power.SchDoc, RC-XD(VX).PrjPcb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]
2026-05-07 Updated main.c, btm9011.c and btm
    [RC-XD(VX).PrjPcb, RX.PcbDoc, RX_C6 Debug.cfg]
2026-05-07 3D files
    [Aku korpus.f3d, Aku korpus.step, Esiratas.f3d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]
2026-05-20 SRX and VTX
    [RC-XD(SRX).PrjPcb, SRX.PcbDoc, SRX.SchDoc]
2026-05-25 ReadMe update
    [RC-XD(VX).PrjPcb, SRX.PcbDoc, VX.PcbDoc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]

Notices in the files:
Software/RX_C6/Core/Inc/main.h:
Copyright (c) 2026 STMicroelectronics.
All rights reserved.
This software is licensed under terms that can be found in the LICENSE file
